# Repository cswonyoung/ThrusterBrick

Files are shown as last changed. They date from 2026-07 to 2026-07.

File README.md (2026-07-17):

# ZnO Nanovoid Process — document set

**Author:** Croft Swonyoung
**License:** CC0 1.0 Universal (public domain dedication) — see `LICENSE`
**Contents:** two application lines in one set — `docs-rotor/` (150 mm rotor/generator, 19 files, complete) and `docs-flight/` (300 mm flying machine, under construction). See `MANIFEST.md`.

To the extent possible under law, Croft Swonyoung has waived all copyright and
related or neighbouring rights to every file in this set and dedicated them to
the public domain worldwide. You may copy, modify, build on, and redistribute
them, including commercially, without permission. **No warranty** — see `LICENSE`.

## Cite / DOI
Archived on Zenodo: **10.5281/zenodo.21224278** —
<https://doi.org/10.5281/zenodo.21224278>

## What's here
- `docs-rotor/` — the 150 mm **rotor / generator** line (19 documents, complete).
- `docs-flight/` — the 300 mm **flying-machine** line (under construction; a
  re-derivation plan + a seed integration SOP so far). Every document in both
  directories carries the CC0 dedication and the author's name inline (a banner in
  the HTML/Markdown files; a comment header in the DXF cut files).
- `LICENSE` — full CC0 1.0 legal code.
- `NOTICE.md` — short human-readable dedication + a note on patents/prior art.
- `MANIFEST.md` — the file list with descriptions.
- `CHANGELOG.md` — version history (what changed in each release).
- `CHECKSUMS.sha256` — SHA-256 of every file (integrity + the timestamping anchor).
- `TIMESTAMPING.md` — how the dated proof works and the one command to create it.
- `UPLOAD-CHECKLIST.md` — step-by-step durable-publication guide.

## Verify integrity
```
sha256sum -c CHECKSUMS.sha256
```

## Reproduce / publish
See `UPLOAD-CHECKLIST.md`. Short version: fill the date in `NOTICE.md`, run
`ots stamp CHECKSUMS.sha256`, then push copies to several independent archives
(Zenodo for a DOI, GitHub + a mirror → Software Heritage, Internet Archive,
Arweave/IPFS).

## Scope note
These documents describe the *fabrication* of a stacked nickel "nanovoid"
structure (grow ZnO nanotips → seed → electroless Ni-P → strip the template →
bond each foil to a silicon wafer → stack and seal the wafer cells under a common
vacuum). They specify how to build the article; they
do not, by themselves, establish what net energy or other output the finished
article produces. Anyone reproducing the work should measure inputs and outputs
directly, with controls. Open publication under CC0 is what makes that
independent verification possible.

This set covers **two end-use lines** built from the same fabrication chemistry:
- **`docs-rotor/` — 150 mm rotor / generator line** (complete). Includes an
  application-integration procedure, `ZnO-SOP-070` (a self-driven rotor test rig).
- **`docs-flight/` — 300 mm flying-machine line** (under construction). The wafer
  size cascades through the whole fabrication chain, so this line is re-derived on
  its own datum — see `docs-flight/300mm-re-derivation-plan.md`.

The integration procedures describe **test rigs for measuring the hypothesised
force**, written to be safe and informative whether or not any net force exists,
and claiming nothing.

## Background & attribution
The tapered-nanocavity geometry in this process is motivated by:

> M. E. McCulloch, "Can Nano-Materials Push Off the Vacuum?",
> *Progress in Physics*, **16** (2), 92–93 (2020).

which argues — from the theory of *quantised inertia* (QI) — that arrays of
asymmetric sub-~129 nm cavities could experience a net force from the quantum
vacuum. Quantised inertia is a non-mainstream theory and the predicted effect is
unverified; this set documents only the *fabrication* of such a structure.
Whether a finished stack produces any net force is an open question to be settled
by direct measurement (see the scope note above). Credit for the underlying idea
is McCulloch's; responsibility for reducing it to a build process — and for any
errors in doing so — is the author's.

Documentation for this release was prepared with assistance from Claude
(Anthropic), reflected in the git commit history.

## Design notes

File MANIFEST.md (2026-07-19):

# Manifest — ZnO Nanovoid Process document set

All files are dedicated to the public domain under CC0 1.0 (see `LICENSE`). This
one set covers **two end-use lines** built from the same fabrication chemistry,
in two directories:

- **`docs-rotor/` — 150 mm rotor / generator line** (19 files, complete).
- **`docs-flight/` — 300 mm flying-machine line** (under construction).

## `docs-rotor/` — 150 mm rotor / generator line

| # | File | Description |
|---|---|---|
| 1 | `ZnO-DR-001_carrier_bath_design_reference.html` | Carrier & bath design reference (round) |
| 2 | `ZnO-DR-002_carrier_build_detail.html` | Carrier build detail (round plates, circular O-ring) |
| 3 | `ZnO-DR-003_immersion_carrier_cut_set.html` | Immersion & seeding carrier cut set (round) |
| 4 | `ZnO-DR-004_carrier_cutfile_nesting.html` | Carrier cut-file nesting (round) |
| 5 | `ZnO-DR-005_strip_carrier_cut_set.html` | Strip carrier cut set (round) |
| 6 | `ZnO-DR-006_wafer_chuck_cut_set.html` | Wafer bonding chuck cut set |
| 7 | `ZnO-SOP-010_nanotip_growth_10mM_depletion.md` | SOP-010 ZnO nanotip growth (10 mM depletion; ⌀156 / 0.15 mm Zn) |
| 8 | `ZnO-SOP-020_APTES_Ag_seeding.md` | SOP-020 APTES functionalisation & Ag seeding |
| 9 | `ZnO-SOP-030_electroless_NiP_plating.md` | SOP-030 electroless Ni-P plating |
| 10 | `ZnO-SOP-040_caustic_strip_clean_dry.md` | SOP-040 caustic strip / bulk clean / dry |
| 11 | `ZnO-SOP-050_phase1_wafer_bond_rim_trim.md` | SOP-050 Phase-1 wafer die-attach, chemical de-rim & final clean |
| 12 | `ZnO-SOP-060_phase2_vacuum_stack_close.md` | SOP-060 Phase-2 common-vacuum stack close (+ App. A application-agnostic ruggedization variant) |
| 13 | `ZnO-SOP-070_rotor_generator_integration.md` | SOP-070 Rotor integration & commissioning (self-driven rotor / thrust-hypothesis test) |
| 14 | `ZnO-SP-001_consolidated_shop_packet.html` | Consolidated shop packet |
| 15 | `ZnO_cut_PP_half.dxf` | Cut file — 1/2 in PP (strip backer, round) |
| 16 | `ZnO_cut_PP_threeEighth.dxf` | Cut file — 3/8 in PP (strip clamp frame, round) |
| 17 | `ZnO_cut_PVDF_quarter.dxf` | Cut file — 1/4 in PVDF (immersion/seeding carrier, round) |
| 18 | `ZnO_cut_frame_PVDF.dxf` | Cut file — PVDF clamp frame (RETIRED — no butyl mask) |
| 19 | `ZnO_cut_platen_alum.dxf` | Cut file — aluminium wafer bonding chuck |

## `docs-flight/` — 300 mm flying-machine line (🚧 under construction)

Naming: the 150 mm step numbers with a `-300` suffix (e.g. `ZnO-SOP-010-300`).

| File | Description | Status |
|---|---|---|
| `300mm-datum-reference.md` | Master datum — the locked dimensions every 300 mm doc cites | **locked** (a few `[confirm]`s) |
| `300mm-re-derivation-plan.md` | What changes from the 150 mm datum, per document | working plan |
| `ZnO-SOP-010-300_nanotip_growth_10mM_depletion.md` | SOP-010 ZnO nanotip growth (⌀306 blank, 4–6 L bath; ZnO seed layer) | **re-derived** (Rev 1.1) |
| `ZnO-SOP-020-300_APTES_Ag_seeding.md` | SOP-020 APTES functionalisation & Ag seeding | **re-derived** (Rev 1.0) |
| `ZnO-SOP-030-300_electroless_NiP_plating.md` | SOP-030 electroless Ni-P plating (⌀280 active; ~8–12 L bath) | **re-derived** (Rev 1.0) |
| `ZnO-SOP-040-300_caustic_strip_clean_dry.md` | SOP-040 caustic strip / bulk clean / dry (void-clear time unchanged) | **re-derived** (Rev 1.0) |
| `ZnO-SOP-050-300_phase1_wafer_bond_rim_trim.md` | SOP-050 Phase-1 wafer die-attach (300 mm wafer), de-rim & clean | **re-derived** (Rev 1.0) |
| `ZnO-SOP-060-300_phase2_vacuum_stack_close.md` | SOP-060 Phase-2 common-vacuum stack close (+ App. A ruggedization, 300 mm) | **re-derived** (Rev 1.0) |
| `ZnO-SOP-080-300_flying_vehicle_integration.md` | Flying-vehicle integration (staged lift demonstrator) | **seed** — still 150 mm-based; re-derive |
| `ZnO-DR-001-300_carrier_bath_design_reference.html` | Carrier & bath design reference | **re-derived** (Rev 1.0) ¹ |
| `ZnO-DR-002-300_carrier_build_detail.html` | Carrier build detail | **re-derived** (Rev 1.0) ¹ |
| `ZnO-DR-003-300_immersion_carrier_cut_set.html` | Immersion & seeding carrier cut set | **re-derived** (Rev 1.0) ¹ |
| `ZnO-DR-004-300_carrier_cutfile_nesting.html` | Carrier cut-file nesting (500 × 600 bed, 1 plate/sheet) | **re-derived** (Rev 1.0) ¹ |
| `ZnO-DR-005-300_strip_carrier_cut_set.html` | Strip carrier cut set | **re-derived** (Rev 1.0) ¹ |
| `ZnO-DR-006-300_wafer_chuck_cut_set.html` | Wafer bonding chuck cut set (⌀300; no waterjet) | **re-derived** (Rev 1.0) ¹ |
| `ZnO-SP-001-300_consolidated_shop_packet.html` | Consolidated shop packet (300 mm; ZnO seed layer at op 10) | **re-derived** (Rev 1.1) |
| `ZnO_cut_PP_half_300.dxf` | Cut file — 1/2 in PP strip backer (⌀350 carrier; ×16 M4 on ⌀330) | **generated** ✓ |
| `ZnO_cut_PP_threeEighth_300.dxf` | Cut file — 3/8 in PP strip clamp frame (window ⌀280) | **generated** ✓ |
| `ZnO_cut_PVDF_quarter_300.dxf` | Cut file — 1/4 in PVDF immersion/seeding carrier (2 beds: window+handle, back/mask) | **generated** ✓ |
| `ZnO_cut_platen_alum_300.dxf` | Cut file — aluminium wafer chuck (⌀340 / recess ⌀300.5; no waterjet) | **generated** ✓ |
| `ZnO_cut_PP_half_300.svg` | To-scale plan (generated) — strip backer | drawing |
| `ZnO_cut_PP_threeEighth_300.svg` | To-scale plan (generated) — strip clamp frame | drawing |
| `ZnO_cut_PVDF_quarter_300.svg` | To-scale plan (generated) — immersion/seeding carrier (2 beds) | drawing |
| `ZnO_cut_platen_alum_300.svg` | To-scale plan (generated) — wafer chuck | drawing |
| `gen_round_dxf_300.py` | Parametric generator — emits the DXF cut set + to-scale SVG plans from the datum (stdlib; validate DXFs with ezdxf) | tool |

¹ Text/table dimensions are on the 300 mm datum. Each cut-set/nesting doc now embeds a **to-scale plan generated from the DXF geometry** (`ZnO_cut_*_300.svg`); the remaining hand drawings are schematic context.

**The 300 mm fabrication line and tooling are complete:** SOP-010–060-300,
DR-001–006-300, SP-001-300, the DXF cut set, and the reproducible **generator +
to-scale plan drawings**, all at the locked datum. DXFs validated with ezdxf.
(`ZnO_cut_frame_PVDF` stays retired — no 300 mm version.) Remaining: the
flying-integration procedure `ZnO-SOP-080-300` is still a 150 mm-based **seed**,
to be re-derived when the flyer / airframe is defined.

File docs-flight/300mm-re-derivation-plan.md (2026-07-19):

# 300 mm re-derivation plan — flying-machine line

Working plan for deriving the 300 mm flight line (`docs-flight/`) from the
established 150 mm rotor line (`../docs-rotor/`) in this same repository. The
**chemistry is unchanged**; what changes is geometry,
tooling, bath scale, and mass. Numbers below are **scaled estimates to confirm**,
not final — decisions the maker must lock are flagged **[DECIDE]**.

> **Tracking note:** the 150 mm line is a moving target — when a rotor-line SOP
> revs, the corresponding `-300` doc must track it (e.g. the **ZnO seed layer**
> added at 150 mm Rev 3.0 was carried into `ZnO-SOP-010-300` Rev 1.1; see §2).

## 1. Datum change (150 mm → 300 mm)

| Parameter | 150 mm (current) | 300 mm (proposed) | Note |
|---|---|---|---|
| Wafer diameter | ⌀150.0 | **⌀300.0** | — |
| Wafer thickness | 0.675 mm | **0.775 mm** | SEMI standard for 300 mm — **[DECIDE/confirm]** |
| Active (etched) region | ⌀130 (10 mm margin) | **⌀280** (keep 10 mm margin) | or scale margin → ⌀260 **[DECIDE]** |
| Zinc foil thickness | 0.15 mm | **0.15 mm (unchanged)** | template thickness is wafer-independent — **[confirm]** |
| Zinc handling rim | 13 mm | **13 mm (unchanged)** | or scale **[DECIDE]** |
| Zinc blank | ⌀156 | **⌀306** | = active ⌀280 + 2×13 rim |
| Ni-P thickness | 25 µm | **25 µm (unchanged)** | thickness is diameter-independent |
| Per-cell pitch | ≈0.78 mm | **≈0.875 mm** | wafer 0.775 + Ni-P 0.025 + bond ~0.075 |
| Per-cell mass | ≈32 g | **≈140 g** | ~4.4× (Si ⌀300×0.775 ≈128 g + Ni-P ≈12 g + bond) |
| Active area / cell | (⌀130) | **~4.6×** | (280/130)² — drives thrust *and* handling |

## 2. Per-document work

**Fabrication chain (re-derive each at the new datum):**
- **SOP-010** (ZnO growth) — ⌀306 zinc blank; bath volume ~4× (vessel ⌀360–400+);
  growth chemistry unchanged, immersion geometry scaled. **Done through Rev 1.1**,
  which tracks the 150 mm Rev 3.0 **ZnO seed layer** (zinc-acetate coat + 300 °C
  anneal, replacing bare-foil self-seeding for c-axis-vertical uniformity): recipe
  identical at both scales; what scales at 300 mm is the handling — ~10–15 mL per
  flood coat, a ≥ ⌀320 anneal plate with **oven preferred** over a hotplate for
  edge-to-edge temperature, and centre-to-edge seed-tint QC. No acid contact after
  seeding (ZnO dissolves in weak acids).
- **SOP-020** (APTES + Ag seed) — seeding carrier scaled to ⌀306; glovebox/vapour
  chamber must clear the larger coupon; reagent volumes ~4×.
- **SOP-030** (electroless Ni-P) — bath ~4× (~6–10 L; vessel ⌀360–400+); plating
  chemistry and 25 µm target unchanged; longer fill/agitation for the larger area.
- **SOP-040** (caustic strip / clean / dry) — strip time set by **area not
  thickness**, so ~4× the H₂/zincate load and bath charge; the ~10–12 h
  void-clearing is void-geometry-limited (unchanged); larger dry fixtures.
- **SOP-050** (Phase-1 wafer bond + de-rim) — ⌀300 wafer chuck; bigger bond fixture;
  chemical de-rim self-stops at ⌀280; handle 300 mm wafer fragility.
- **SOP-060** (Phase-2 vacuum stack close) — ⌀300 stack; envelope + chamber sealer
  must clear ⌀300+; getter sized to ~4× area/outgassing; platens ⌀≥300 (step to
  ¼″ likely needed for flatness under load); **N and mass budget re-computed** (see §3).

**Design references (rewrite to the ⌀306 datum, bump revs):**
- **DR-001…005** — carrier/bath/immersion/strip references at the new diameter;
  larger vessels; re-do nesting (a ⌀340+ carrier likely = 1 plate per larger sheet).
- **DR-006** — wafer bonding chuck for 300 mm.

**DXF cut set (regenerate all at the new datum):**
- Carrier plate: outer ~⌀340–360 **[DECIDE]**, window ⌀280, coupon pocket ⌀306.3,
  O-ring groove ~⌀293, bolt circle ~⌀324 ×16 M4 **[DECIDE]** (more bolts for the
  larger plate); PP/PVDF backer + clamp frame scaled; aluminium wafer chuck → ⌀300.
- New/larger stock sizes — confirm bed/sheet size against your cutter.

**Application integration:**
- **SOP-080** (flying-vehicle) — re-derive against the 300 mm ruggedized puck
  handoff (§4) and the new masses; complete the `[TBD]` fields (per-puck thrust,
  vehicle mass, T/W). Currently in `docs/` as a 150 mm-based **seed**.

**Consolidated shop packet:**
- **SP-001** — full rewrite to the 300 mm datum (index, purchasing, station list,
  bath volumes, fixtures).

## 3. Mass / stack recompute (flyer-critical)

- Per-cell ≈140 g at 0.875 mm pitch. A stack of N cells ≈ **0.14N kg** active +
  platens + envelope/getter.
- **Honest scaling caveat:** active area (~4.6×) and cell mass (~4.4×) scale
  *together*, so going to 300 mm raises **absolute** thrust and mass in step —
  **thrust-to-weight is roughly scale-invariant.** The 300 mm choice buys larger
  absolute thrust per layer and fewer cells/interfaces for a given area, **not**
  a better lift ratio. Confirm the intended rationale before committing, and keep
  T/W > 1 as the open, to-be-measured question (SOP-080).

## 4. Ruggedization at 300 mm (SOP-060 Appendix A equivalent)

- Edge-cushion **rim strip**: width = stack height H; length = π(D + s) ≈
  **π(301) ≈ 946 mm**; same 50 A / 1.0 mm platinum-silicone, E595, vacuum-baked.
- Optional recessed **end-ring**: OD 300, ID ≥ (active ⌀280 + margin), recessed
  into the platen (never proud in the preload path).
- **Carrier pot**: larger, heavier; same filled low-exotherm epoxy discipline;
  CoG/mass budget set by the flyer's needs, not a rotor's 128 G.

## 5. Equipment / cost implications

- ~4× reagent volumes; vessels, glovebox, and **chamber sealer** all sized for
  ⌀300+ — the sealer clearance is a likely long-lead/cost item.
- 300 mm wafers: higher unit cost, more fragile handling, larger clean staging.

### 5.1 Cutter (router) bed sizing
The bed size is driven by the largest single part — the **shared carrier plate**.
On the 150 mm line that plate is ⌀190 (⌀156 coupon) and cuts ~1/sheet on a
~300 × 287 mm bed. At 300 mm the coupon (zinc blank) is ⌀306, so the carrier
scales to roughly **⌀350–380** (straight 2× → ⌀380; coupon ⌀306 + the same
absolute land/bolt-circle margins → ⌀340–356). Add ~30–50 mm workholding all
round → stock blank ~⌀450–480.

| Usable cutting envelope | Fit |
|---|---|
| ~**500 × 500 mm** (minimum) | one ⌀380 carrier with clamps; tight |
| ~**600 × 600 mm** (24″×24″, recommended) | carrier + companion parts (clamp frame, backer) without re-fixturing |
| ~**600 × 900** or **1220 × 1220** (4′×4′) | nesting / full-sheet stock |

Heuristic: **≈ double each dimension of the current ~300 × 287 bed → ~600 × 600**.

**DECIDED (2026-07-15):** target a standard **500 × 600 mm** bed. The carrier is
held to ⌀≤~380 to fit with clamp margin; **lock the carrier at ⌀350** (see
`300mm-datum-reference.md`) so clamping stays comfortable on the 500 mm axis (use
the 600 mm axis for clamp length; ⌀350 + ~2×50 mm ≈ ⌀450 blank fits 500 × 600).

**Caveat — the aluminium chuck needs another machine.** The carriers are plastic
(PVDF/PP/PEEK) and suit the 500 × 600 router. The **aluminium wafer chuck at
⌀300+** is a heavier cut; **waterjet is ruled out on cost**, so the options are a
**rigid mill**, a **slow router pass** (right bit/feeds, stepped depths),
**outsourcing** just that part, or reconsidering the chuck material (a thick, flat
polymer or cast tooling-plate alternative) — decide when the chuck is designed.

## 6. Open decisions (flag before building)

1. Wafer thickness (0.775 mm standard vs thinned) — **default 0.775 mm** in the
   datum reference; confirm.
2. Active-region margin (fixed 10 mm → ⌀280, or scaled) — **default 10 mm** (⌀280);
   confirm.
3. Zinc rim width and blank ⌀306 vs scaled — **default 13 mm → ⌀306**; confirm.
4. Carrier outer ⌀ and bolt pattern — **RESOLVED: ⌀350 outer, bolt circle ⌀330 ×16
   M4** (bounded by the 500 × 600 bed; see the datum reference); confirm bolt
   count/size against your cutter.
5. **Numbering — RESOLVED:** `-300` suffix on the 150 mm step numbers
   (`ZnO-SOP-010-300`, `ZnO-DR-001-300`, `ZnO_cut_<part>_300.dxf`).
6. **300 mm rationale — RESOLVED:** handling / throughput (fewer, larger parts per
   unit active area); T/W ~scale-invariant, so the win is process efficiency, not
   lift ratio.

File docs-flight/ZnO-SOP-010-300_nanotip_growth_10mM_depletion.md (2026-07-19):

<!-- Public Domain Dedication: CC0 1.0 Universal -->
> **Public Domain · CC0 1.0 Universal.** Author: **Croft Swonyoung**. To the extent possible under law, the author has waived all copyright and related or neighbouring rights to this document and dedicates it to the public domain worldwide (CC0 1.0). No warranty. See `LICENSE` or <https://creativecommons.org/publicdomain/zero/1.0/>.
>
> Part of the *ZnO nanovoid process* document set (300 mm flying line). Verify file integrity against `CHECKSUMS.sha256`.

---

> **300 mm line · derived from the 150 mm `ZnO-SOP-010` Rev 3.0.** The growth
> **chemistry, seed-layer recipe, temperatures, and target tip geometry are identical**
> to the 150 mm procedure — only the **substrate blank, vessel, bath volume, and
> seed-coat/anneal handling** scale with the larger wafer. All dimensions come from
> `300mm-datum-reference.md`; this SOP does not restate them independently.

---

# Working Bath Procedure & Specification

## Seeded Hydrothermal Growth of ZnO Nanotips on Zinc Foil (300 mm)
### 10 mM Equimolar Zn(NO₃)₂·6H₂O / HMTA — Depletion Run (ZnO seed layer; no post-growth acid etch)

| Field | Value | Field | Value |
|---|---|---|---|
| Document no. | ZnO-SOP-010-300 | Revision | 1.1 |
| Effective date | ____________ | Supersedes | Rev 1.0 |
| Author | Croft Swonyoung | Approved by | ____________ |
| Process | ACG / hydrothermal | Deposit face | One side (back masked) |

---

## 1. Purpose and scope

This procedure grows a dense, vertically oriented array of ZnO nanotips on one face of zinc foil by seeded aqueous chemical (hydrothermal) growth. A **ZnO seed layer** — zinc-acetate-derived nanocrystals coated onto the cleaned foil and annealed (§6.3) — sets a dense, uniform, (0001)-up nucleation template, so rod orientation is decoupled from the random grain orientations of the rolled foil and the array comes out c-axis vertical with a tight size distribution. A single charge of dilute (10 mM) equimolar zinc nitrate / hexamethylenetetramine solution is then held at 90 °C and run to depletion; the declining supersaturation of the depleting bath produces the tapered tips without any post-growth acid treatment.

**Target geometry (per crystal):** base 70–120 nm (measured across the hexagonal flats), height < 300 nm, tapered to a point, densely packed, c-axis vertical. *(Unchanged from the 150 mm line — tip geometry is set by the bath chemistry, not the coupon size.)*

**Substrate:** zinc foil, **0.15 mm thick**, cut as a **⌀306 round blank** (the downstream etch/plate/strip flow defines a **⌀280 active area** inside a **13 mm handling rim**, to back a **300 mm silicon wafer** — see `300mm-datum-reference.md`). Mounted in a carrier that masks the reverse face so growth occurs on one side only.

---

## 2. Definitions and interpretation

- **"Acid etch" (post-growth)** — the tip-sharpening step applied *after* growth — is deliberately omitted here; taper is obtained from bath depletion alone.
- **Light etch (pre-growth)** — a brief, separate dilute-**acetic-acid** dip *before* growth (§6.2) that strips the native oxide and presents a fresh surface for the seed coat. It is retained, and is **not** the same step as the omitted post-growth etch. Nucleation density is set primarily by the seed layer, not the etch.
- **ZnO seed layer (pre-growth)** — a coat of ~5–10 nm ZnO nanocrystals formed by flood-coating the cleaned foil with dilute zinc acetate in ethanol and annealing at ~300 °C (§6.3). The seeds carry a (0001)-up texture, so rods nucleate dense, uniform, and c-axis vertical regardless of the foil's grain orientations. **Because ZnO dissolves in weak acids, no acid may contact the foil after the seed layer is applied.** *Naming:* always write "ZnO seed layer" for this step — the *silver seeding* of ZnO-SOP-020-300 (catalytic seed for electroless Ni-P) is a different step, and the two must stay unambiguous across the document set.
- **Depletion run:** running the fresh bath until the zinc precursor is spent and no fresh precipitate forms. A single, un-replenished charge self-limits rod height, which is how sub-300 nm height is held.
- **Base diameter:** dimensions are stated face-to-face (across flats). Across corners is ~1.155× larger; fix the across-flats convention for all SEM measurements.

---

## 3. Health, safety and environment

Consult the SDS for each reagent before starting. Key hazards:

- **Hexamethylenetetramine (HMTA)** — flammable solid; on heating in water it releases formaldehyde and ammonia. Weigh and run in a fume hood.
- **Zinc nitrate hexahydrate** — oxidiser; skin/eye/respiratory irritant. Keep away from combustibles.
- **Dilute acetic acid** (light-etch dip, ~2–5 % v/v) — irritant to eyes and skin at working strength; pungent vapour. Gloves and goggles. The **glacial acetic acid concentrate** used to make dilutions is corrosive and combustible — dilute in a fume hood, and always add acid to water, never water to acid.
- **Hot solution** — the 90 °C aqueous bath is a burn/scald hazard, and at 300 mm the **bath is ~4× larger (4–6 L) and heavier** — use a stable, well-supported vessel and safe lifting practice. Use a loosely covered (vented) vessel; never seal a hot bath and keep ≤ 95 °C to avoid pressure build-up.
- **Absolute ethanol** (seed solution and inter-coat rinse) — highly flammable liquid and vapour. Keep away from hot surfaces and all ignition sources; work with small volumes; cap containers. Complete all ethanol steps and let the face dry **before** the anneal heat-up.
- **Zinc acetate dihydrate** — eye/skin irritant; zinc-bearing (heavy-metal waste stream).
- **Seed anneal (~300 °C)** — severe burn hazard; at 300 mm the anneal plate is large (≥ ⌀306) and holds substantial heat — it and the foil stay hot long after heating stops. Handle with tongs/heat gloves and allow full cool-down.
- **PPE:** nitrile gloves, safety goggles, lab coat; all HMTA weighing and bath heating in a fume hood.
- **Waste:** the spent bath carries dissolved and particulate zinc (now ~4× the volume). Collect as aqueous heavy-metal waste; do not pour to drain. Neutralise/dispose per local regulations. Spent etch dip carries dissolved zinc acetate — same heavy-metal stream.

---

## 4. Materials, reagents and equipment

### 4.1 Reagents

- Zinc nitrate hexahydrate, Zn(NO₃)₂·6H₂O, ACS grade (M = 297.48 g/mol).
- Hexamethylenetetramine (HMTA), C₆H₁₂N₄, ≥ 99 % (M = 140.19 g/mol).
- Deionised water, Type I/II (≥ 18 MΩ·cm preferred), for bath make-up and rinsing.
- Acetone and isopropanol (IPA), reagent grade, for degreasing.
- Dilute acetic acid, ~2–5 % v/v (≈ 0.35–0.9 M), for the pre-growth light etch; dilute from glacial acetic acid (≥ 99 %) with DI water.
- Zinc acetate dihydrate, Zn(CH₃COO)₂·2H₂O, ACS grade (M = 219.51 g/mol), for the seed solution.
- Absolute ethanol (≥ 99.5 %), for seed-solution make-up and the inter-coat rinse.
- Dry nitrogen (or clean, oil-free compressed air) for drying.

### 4.2 Equipment

- Hotplate or water/oil bath, stable to 90 ± 2 °C, **sized for the larger 4–6 L charge** (heat-up is slower — allow for it), with a calibrated thermometer/thermocouple in the bath.
- **Wide inert growth vessel** (borosilicate or PP) able to submerge the **⌀306 foil with ~10–20 mm clearance — inner ⌀ ~340–360 mm**, ~4–6 L, with a loose lid/watch-glass cover.
- Substrate carrier that masks the reverse face and holds the **⌀306** foil face-down or tilted 15–45° (a larger, floppier coupon than the 150 mm line — support it fully to keep it flat; see §6.6).
- Heat source capable of **300 ± 25 °C across the full ⌀306 blank** for the seed anneal: a flat aluminium anneal plate **≥ ~320 mm** on a hotplate large enough to heat it evenly, or (preferred at this size for temperature uniformity) a lab/convection oven that accepts the plate flat; tongs/heat gloves.
- Pipette (~10–20 mL) and ethanol wash bottle for the seed coats; a clean, level surface large enough for the ⌀306 blank.
- Analytical balance (0.1 mg), volumetric glassware, PTFE-tipped tweezers, timer, sonicator large enough for the ⌀306 coupon, drying stand.

---

## 5. Bath specification

| Parameter | Specification | Notes / tolerance |
|---|---|---|
| Chemistry | Zn(NO₃)₂·6H₂O + HMTA, equimolar | 1 : 1 molar ratio |
| Concentration | 10 mM each | Dilute — thin bases, low per-rod budget |
| Solvent | Type I/II DI water | ≥ 18 MΩ·cm preferred |
| Zn(NO₃)₂·6H₂O loading | 2.975 g per litre | = 0.010 mol/L × 297.48 g/mol |
| HMTA loading | 1.402 g per litre | = 0.010 mol/L × 140.19 g/mol |
| As-mixed pH | ~5.5–6.5 | Do not adjust; not externally buffered |
| Temperature | 90 °C | Acceptable 88–92 °C; never seal, ≤ 95 °C |
| Agitation | Static (no stirring) | Convection re-feeds supersaturation and blunts tips |
| Charge | Single, un-replenished | Defines zinc budget → self-limited height |
| Run mode | Run to depletion | End when solution clears / no fresh precipitate |
| Typical run time | ~45–90 min | **Calibrate on first run;** record actual time |
| Substrate orientation | Face-down or tilted | Lets homogeneous particles fall clear of the face |

> **Concentration and temperature are unchanged from the 150 mm line** — the per-rod
> zinc budget that sets tip geometry is a *concentration* effect, independent of
> coupon size. The larger coupon simply needs more litres of the same 10 mM bath.

### 5.1 Reagent quantities by bath volume

| Bath volume | Zn(NO₃)₂·6H₂O | HMTA |
|---|---|---|
| 4.0 L | 11.900 g | 5.608 g |
| 5.0 L | 14.875 g | 7.010 g |
| 6.0 L | 17.850 g | 8.412 g |

**Sizing:** use the smallest volume that fully submerges the ⌀306 foil with ~10–20 mm clearance — typically **~4–6 L** in a ~⌀340–360 mm vessel. Scale masses linearly: mass = (2.975 g/L Zn(NO₃)₂ or 1.402 g/L HMTA) × volume in L.

### 5.2 Seed solution specification

*(Chemistry identical to the 150 mm line — only the per-coat flood volume scales with the ⌀306 face.)*

| Parameter | Specification | Notes / tolerance |
|---|---|---|
| Chemistry | Zn(CH₃COO)₂·2H₂O in absolute ethanol | Seed coat only — never enters the growth bath |
| Concentration | 5 mM | **0.110 g per 100 mL** ethanol |
| Make-up | Dissolve with brief sonication or mild warming (< 40 °C) | Must be fully clear before use |
| Coats | 3–5 flood coats, **~10–15 mL each** for the ⌀306 face | Each: flood 10–20 s → ethanol rinse → N₂ dry (§6.3) |
| Anneal | 300 ± 25 °C, 20–30 min, in air | Decomposes acetate to ~5–10 nm ZnO seeds, (0001)-up texture |
| Shelf life | ≤ ~1 week, sealed | Make fresh preferred; discard if hazy (slow hydrolysis) |

---

## 6. Procedure

### 6.1 Blank the round substrate

Cut the **⌀306 round zinc blank** from 0.15 mm zinc foil stock **before** any cleaning. The cut sits 13 mm outside the ⌀280 active zone, so it never touches the nanostructured area, and the rim it forms is sacrificial (dissolved at the ZnO-SOP-050-300 de-rim) — so edge finish is uncritical. The one spec that matters is that the blank drops cleanly into the carriers' **⌀306.3 locating pocket** (ZnO-DR-003-300 / ZnO-DR-005-300).

1. **Method (in order of preference for a ⌀306 disc):**
   - **Adjustable rotary circle cutter** — set to **153 mm radius** on a backing mat; no tooling, and practical at this larger diameter (a ⌀306 steel-rule die or punch is large and costly). Hand-guided, so verify roundness/diameter.
   - **Custom ⌀306 steel-rule die / hollow punch** — ideal repeatability for batches if the tooling cost is justified; press-driven.
   - *(Laser is acceptable but zinc fume needs extraction.)* **Do not use the CNC router** — it deflects and grabs 0.15 mm foil and throws swarf; the larger, floppier ⌀306 blank is even more prone to this.
2. **Backing:** cut over end-grain wood, a poly cutting board, or a self-healing mat so the blade fully severs the foil without tearing.
3. **Burr:** orient the tool so any burr lands on the **rim** (the sacrificial, de-rimmed side); knock down a burr that would keep the blank from seating.
4. **Fit check:** confirm the blank is round and drops flush into the ⌀306.3 carrier pocket; deburr or retrim if proud. **Flatness:** the larger blank is floppier — keep it flat during handling and store between flat supports.
5. Handle by the rim only; keep the future growth face clean.

### 6.2 Substrate preparation — before-growth cleaning

1. Handle the foil only with PTFE-tipped tweezers by an edge; never touch the growth face. The ⌀306 coupon is large — support the whole disc during transfers so it does not fold.
2. Sonicate 5 min in acetone.
3. Sonicate 5 min in fresh isopropanol.
4. Sonicate 5 min in DI water to remove solvent residue.
5. **Light etch:** dip 15–30 s in dilute acetic acid (~2–5 % v/v) to strip the native oxide and open nucleation sites. **Calibrate the time on the first run** and keep it a controlled parameter; over-etching still thins and roughens the foil.
6. **Immediately** rinse under copious flowing DI water to stop the etch; do not let the freshly etched surface sit in air.
7. Blow dry at once with N₂ (or clean air), sheeting water off the face to avoid spots.
8. Proceed **immediately** to the seed-layer coat (§6.3); do not let the freshly etched surface sit in air. (Carrier mounting now happens after the seed anneal — §6.3 step 8.)

> **Note — light etch.** Removing the passivating native oxide presents a fresh, wettable surface for the seed coat; the post-growth tip-sharpening etch remains omitted. ZnO dissolves readily in weak organic acids — which is also why **no acid may touch the foil after §6.3**. With the seed layer setting nucleation density, over-etching gains nothing: hold to the short end of the dip window unless wetting is visibly poor.

### 6.3 ZnO seed layer (coat and anneal)

Rolled zinc foil is polycrystalline with random grain orientations; rods nucleating directly on bare foil inherit that spread and grow at scattered tilts. This step lays down a dense, uniform template of ~5–10 nm ZnO nanocrystals with (0001)-up texture, so the rods grow c-axis vertical with a tight base-diameter distribution, independent of the grains beneath. Dense, uniform nucleation also self-corrects residual tilt: off-vertical rods run into neighbours and terminate while vertical rods win. Over the ⌀280 active field this matters doubly — orientation and size spread must hold **centre-to-edge**, not just locally.

**No acid contact from this point on — the acetic dip dissolves ZnO seeds.**

1. Perform §6.2 in full (degrease, light etch, rinse, dry) and continue directly — do not pause between etch and first coat.
2. Lay the foil flat, growth face up, on a clean, level surface large enough to support the full ⌀306 disc. Confirm level — on a face this large, an out-of-level surface pools the seed solution to one side and grades the coat.
3. Flood the growth face with seed solution (§5.2) from a pipette — **~10–15 mL for the ⌀306 face**, working quickly edge to edge so the whole face wets before the first-applied region dries. Let stand 10–20 s.
4. Rinse gently with clean absolute ethanol from a wash bottle, then blow dry with N₂, sheeting toward the rim. The rinse is what leaves a sparse adsorbed layer rather than drying rings — **do not skip it.**
5. Repeat steps 3–4 for a total of **3–5 coats**.
6. **Anneal:** lay the foil dead flat on the ≥ ⌀320 aluminium anneal plate, growth face up (weight the rim with a flat ring if it lifts — the large blank is prone to lifting at the edge), ramp gently to **300 ± 25 °C**, hold **20–30 min** in air, then cool slowly in place. An oven is preferred at this size — a hotplate smaller than the plate leaves the rim cold and the seed texture non-uniform; if a hotplate must be used, verify the plate reaches temperature edge-to-edge before counting the hold. Stay far below zinc's 419.5 °C melting point. The face dulls slightly from thermal oxide — acceptable; the entire Zn/ZnO template dissolves at ZnO-SOP-040-300.
7. *Optional density lever (qualify before adopting):* repeat the full coat-set + anneal cycle a second time for denser seeding.
8. Mount in the carrier (reverse face masked) and proceed to bath preparation and growth promptly. The anneal fully softens the zinc — the ⌀306 foil comes off the plate flatter but floppier, and at this diameter it will fold under its own weight if lifted by an edge; slide it onto a flat support and handle by the rim with the disc fully supported.

### 6.4 Bath preparation

1. Charge the vessel with ~90 % of the target DI water volume (4–6 L).
2. Weigh Zn(NO₃)₂·6H₂O and HMTA to the quantities in §5.1; record actual masses.
3. Dissolve the zinc nitrate fully with gentle stirring, then dissolve the HMTA; stir until completely clear.
4. Make up to final volume with DI water. Optionally filter (0.2 µm) to remove stray particulates.
5. Cover and pre-heat the solution to 90 °C — **allow extra time for the larger charge to reach temperature.** Confirm with the in-bath probe before loading the substrate.

### 6.5 Growth run (to depletion)

1. Immerse the carried substrate, growth face down or tilted, into the 90 °C bath. Start the timer (t₀). Ensure no air bubbles are trapped on the face — a larger face traps bubbles more easily, so tilt on entry to sweep them off.
2. Hold at 90 °C, static and loosely covered. Do not stir, agitate, or replenish the bath.
3. Let the run proceed to depletion: the solution turns milky at peak nucleation, then clears as zinc is consumed. Endpoint = a clear (or markedly clarified) bath with no fresh precipitate forming.
4. Record the actual depletion time (expect ~45–90 min on the first calibration run) and the bath temperature profile. **Re-calibrate for this line:** the larger bath and coupon may shift the observed depletion time — treat the first 300 mm run as a fresh calibration.

### 6.6 Recovery — after-growth cleaning

1. At the endpoint, withdraw the substrate promptly, supporting the full ⌀306 disc.
2. Immediately rinse under copious flowing DI water to quench the reaction and float off loosely bound homogeneous particles. Do not wipe or brush the surface.
3. Optional, if loose powder persists: a few seconds of very gentle low-power DI sonication. **Caution** — aggressive sonication dislodges rods; use sparingly and inspect afterward.
4. Blow dry with N₂, holding the foil so water sheets off cleanly; avoid drying spots.
5. Optional consolidation dry: up to ~150–250 °C in air to drive off residual water (gentle ramp; the 0.15 mm foil thickness is unchanged from the 150 mm line, but the **larger ⌀306 disc has more unsupported area and is more warp-prone** — support it flat and ramp gently; stay far below the 419.5 °C zinc melting point). Not required for geometry.
6. Store the finished foil flat between clean flat supports, in a covered container.

---

## 7. Acceptance criteria and QC

- **Seed layer (post-anneal, pre-growth):** uniform faint tint change across the face, **centre-to-edge** — no rings, droplet marks, streaks, bare patches, or a visibly different rim (a cold-rim anneal shows up here). Rings, patches, or a graded tint → re-clean and re-seed before committing the growth run.
- **Visual (post-growth):** uniform matte white/grey coating over the growth face; no bare patches, no thick powdery cake. Over the larger ⌀280 active area, check uniformity **centre-to-edge** (a bigger face is more prone to edge-to-centre gradients from bath convection).
- **SEM (plan + cross-section) — base** (across flats) 70–120 nm; height < 300 nm; tips tapered to a point; densely packed without coalescing into a film; rods c-axis vertical and parallel in cross-section (tilt spread tight — the seeded array should not show splayed rods). Sample **multiple sites across the ⌀280 field**, not just the centre.
- **Process:** spent bath clear at pull; depletion time logged.
- **First-run gate:** the seed layer splits the same 10 mM single charge across more rods, so expect **denser, shorter, thinner** output than the unseeded expectation. Re-calibrate base diameter, height, packing, and verticality by SEM — with **cross-field uniformity** confirmed — on the first seeded 300 mm run before releasing the recipe to routine use.

**Expected first-pass output (10 mM depletion, seeded):** trends denser, shorter, and thinner-based than the unseeded expectation (base ~60–100 nm, height ~250–380 nm, strong taper) — treat those numbers as the upper envelope and let the first seeded run set the new baseline. If height still edges over 300 nm, reduce concentration toward ~8 mM (which depletes sooner and shorter) and re-qualify; if bases fall well under 70 nm, drop to 3 coats.

---

## 8. Troubleshooting

| Observation | Likely cause → corrective action |
|---|---|
| Height > 300 nm | Per-rod zinc budget too high → dilute toward 8 mM; confirm single charge; optionally drop to 88 °C. |
| Bases > 120 nm / merging | Too much lateral growth → lower concentration; verify not double-charged. |
| Bases < 70 nm / sparse | Weak nucleation → add seed coats (3 → 5) or a second coat-set + anneal cycle; verify the anneal reached ≥ ~275 °C across the whole plate (acetate does not fully decompose below that); improve degrease; transfer promptly between steps. |
| Rods tilted / splayed | Seed coat thin or patchy (foil grains showing through) → add coats or a second coat-set + anneal cycle; confirm the ethanol rinse after **every** coat; confirm no acid contact after seeding. |
| Rings / streaks in the array | Seed solution allowed to dry unrinsed, or the coating surface out of level → rinse with clean ethanol after every coat; level the surface; work the flood quickly edge to edge; discard hazy seed solution. |
| **Centre-to-edge non-uniformity** (new at 300 mm) | Seed-side: graded seed coat (out-of-level flood) or cold-rim anneal → level the coating surface; use an oven or verify edge-to-edge plate temperature. Growth-side: convection gradients over the larger face → keep strictly static and level; ensure even immersion depth; consider a deeper bath so the whole face sees similar hydrostatic/thermal conditions. |
| Blunt / flat tips | Bath not truly depleted, or convection re-fed it → confirm run to clear; keep strictly static. |
| Loose powdery deposit | Excess homogeneous nucleation settling on the face → keep face-down; filter make-up; gentler heat-up. |
| Foil thinned / warped / pitted | Light etch too long or acid too concentrated → shorten the dip; dilute the acid; rinse promptly. Support the large disc flat throughout. |
| Rods detached after rinse | Recovery too aggressive → gentler DI rinse; reduce or eliminate sonication. |

---

## 9. Waste and storage

- Collect spent baths and zinc-bearing rinse water (including the spent acetic etch, now zinc acetate solution) as aqueous heavy-metal waste; neutralise and dispose per local regulations. Do not drain-dispose. Volumes are ~4× the 150 mm line — size your waste collection accordingly.
- Spent seed solution and inter-coat ethanol rinses are **zinc-bearing flammable organic waste** — collect separately from the aqueous stream; do not drain-dispose.
- Store unused reagents dry and sealed; HMTA away from heat and ignition; zinc nitrate away from combustibles; glacial acetic acid away from oxidisers and bases; ethanol away from ignition sources; zinc acetate dry.
- Store finished substrates flat (between flat supports), dry, covered, and labelled with run ID and depletion time.

---

## 10. Revision history

| Rev | Date | Author | Change summary |
|---|---|---|---|
| 1.0 | __________ | Croft Swonyoung | **Initial release of the 300 mm flying-line variant, derived from the 150 mm `ZnO-SOP-010` Rev 2.2.** Substrate scaled to a **⌀306 round zinc blank** (⌀280 active + 13 mm rim, backing a 300 mm wafer per `300mm-datum-reference.md`); growth vessel to ~⌀340–360 mm / **4–6 L**; reagent-by-volume table re-tabulated for 4–6 L; blanking method favours the rotary circle cutter (153 mm radius) at this diameter; added centre-to-edge uniformity checks and large-floppy-coupon handling/flatness notes. **Growth chemistry, 10 mM concentration, 90 °C temperature, and target tip geometry are unchanged** — they are concentration/temperature effects independent of coupon size. |
| 1.1 | __________ | Croft Swonyoung | **Tracks the 150 mm `ZnO-SOP-010` Rev 3.0: added the ZnO seed layer** (new §6.3) — 5 mM zinc acetate dihydrate in absolute ethanol, 3–5 flood coats (**~10–15 mL each** at ⌀306) with ethanol rinse each, annealed 300 ± 25 °C / 20–30 min in air on a ≥ ⌀320 flat plate (oven preferred at this size for edge-to-edge temperature). Title changed from *Self-Seeded* to *Seeded*. Light etch retained as surface prep; **no acid contact after seeding**. Carrier mounting moved to after the seed anneal; §6.3–6.5 renumbered §6.4–6.6; seed-solution spec added as §5.2; reagents, equipment, HSE, QC (centre-to-edge seed-tint check; seeded-run recalibration gate), troubleshooting (cold-rim / graded-coat causes), and waste updated. Naming rule: "ZnO seed layer" here vs. "silver seeding" in ZnO-SOP-020-300. |

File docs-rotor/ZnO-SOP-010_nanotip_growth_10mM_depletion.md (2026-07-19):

<!-- Public Domain Dedication: CC0 1.0 Universal -->
> **Public Domain · CC0 1.0 Universal.** Author: **Croft Swonyoung**. To the extent possible under law, the author has waived all copyright and related or neighbouring rights to this document and dedicates it to the public domain worldwide (CC0 1.0). No warranty. See `LICENSE` or <https://creativecommons.org/publicdomain/zero/1.0/>.
>
> Part of the *ZnO nanovoid process* document set. Verify file integrity against `CHECKSUMS.sha256`.

---

# Working Bath Procedure & Specification

## Seeded Hydrothermal Growth of ZnO Nanotips on Zinc Foil
### 10 mM Equimolar Zn(NO₃)₂·6H₂O / HMTA — Depletion Run (ZnO seed layer; no post-growth acid etch)

| Field | Value | Field | Value |
|---|---|---|---|
| Document no. | ZnO-SOP-010 | Revision | 3.0 |
| Effective date | ____________ | Supersedes | Rev 2.2 |
| Author | Croft Swonyoung | Approved by | ____________ |
| Process | ACG / hydrothermal | Deposit face | One side (back masked) |

---

## 1. Purpose and scope

This procedure grows a dense, vertically oriented array of ZnO nanotips on one face of zinc foil by seeded aqueous chemical (hydrothermal) growth. A **ZnO seed layer** — zinc-acetate-derived nanocrystals coated onto the cleaned foil and annealed (§6.3) — sets a dense, uniform, (0001)-up nucleation template, so rod orientation is decoupled from the random grain orientations of the rolled foil and the array comes out c-axis vertical with a tight size distribution. A single charge of dilute (10 mM) equimolar zinc nitrate / hexamethylenetetramine solution is then held at 90 °C and run to depletion; the declining supersaturation of the depleting bath produces the tapered tips without any post-growth acid treatment.

**Target geometry (per crystal):** base 70–120 nm (measured across the hexagonal flats), height < 300 nm, tapered to a point, densely packed, c-axis vertical.

**Substrate:** zinc foil, **0.15 mm thick**, cut as a **⌀156 round blank** (the downstream etch/plate/strip flow defines a ⌀130 active area inside a 13 mm handling rim, to back a 150 mm silicon wafer). Mounted in a carrier that masks the reverse face so growth occurs on one side only.

---

## 2. Definitions and interpretation

- **"Acid etch" (post-growth)** — the tip-sharpening step applied *after* growth — is deliberately omitted here; taper is obtained from bath depletion alone.
- **Light etch (pre-growth)** — a brief, separate dilute-**acetic-acid** dip *before* growth (§6.2) that strips the native oxide and presents a fresh surface. It is retained, and is **not** the same step as the omitted post-growth etch. (Rev 2.0: acetic acid replaces dilute HCl — ZnO dissolves readily in weak organic acids, and the milder acid is gentler on the foil and eliminates HCl vapour handling. Rev 3.0: with the seed layer added, the etch's role is surface preparation for seeding; nucleation density is now set primarily by the seed layer.)
- **ZnO seed layer (pre-growth)** — a coat of ~5–10 nm ZnO nanocrystals formed by flood-coating the cleaned foil with dilute zinc acetate in ethanol and annealing at ~300 °C (§6.3). The seeds carry a (0001)-up texture, so rods nucleate dense, uniform, and c-axis vertical regardless of the foil's grain orientations. **Because ZnO dissolves in weak acids, no acid may contact the foil after the seed layer is applied.** *Naming:* always write "ZnO seed layer" for this step — the *silver seeding* of ZnO-SOP-020 (catalytic seed for electroless Ni-P) is a different step, and the two must stay unambiguous across the document set.
- **Depletion run:** running the fresh bath until the zinc precursor is spent and no fresh precipitate forms. A single, un-replenished charge self-limits rod height, which is how sub-300 nm height is held.
- **Base diameter:** dimensions are stated face-to-face (across flats). Across corners is ~1.155× larger; fix the across-flats convention for all SEM measurements.

---

## 3. Health, safety and environment

Consult the SDS for each reagent before starting. Key hazards:

- **Hexamethylenetetramine (HMTA)** — flammable solid; on heating in water it releases formaldehyde and ammonia. Weigh and run in a fume hood.
- **Zinc nitrate hexahydrate** — oxidiser; skin/eye/respiratory irritant. Keep away from combustibles.
- **Dilute acetic acid** (light-etch dip, ~2–5 % v/v) — irritant to eyes and skin at working strength; pungent vapour. Gloves and goggles. The **glacial acetic acid concentrate** used to make dilutions is corrosive and combustible — dilute in a fume hood, and always add acid to water, never water to acid.
- **Hot solution** — the 90 °C aqueous bath is a burn/scald hazard. Use a loosely covered (vented) vessel; never seal a hot bath and keep ≤ 95 °C to avoid pressure build-up.
- **Absolute ethanol** (seed solution and inter-coat rinse) — highly flammable liquid and vapour. Keep away from the hot hotplate and all ignition sources; work with small volumes; cap containers. Complete all ethanol steps and let the face dry **before** the anneal heat-up.
- **Zinc acetate dihydrate** — eye/skin irritant; zinc-bearing (heavy-metal waste stream).
- **Seed anneal (~300 °C)** — severe burn hazard; the foil and anneal plate stay hot long after heating stops. Handle with tongs and allow full cool-down before touching.
- **PPE:** nitrile gloves, safety goggles, lab coat; all HMTA weighing and bath heating in a fume hood.
- **Waste:** the spent bath carries dissolved and particulate zinc. Collect as aqueous heavy-metal waste; do not pour to drain. Neutralise/dispose per local regulations. Spent etch dip carries dissolved zinc acetate — same heavy-metal stream.

---

## 4. Materials, reagents and equipment

### 4.1 Reagents

- Zinc nitrate hexahydrate, Zn(NO₃)₂·6H₂O, ACS grade (M = 297.48 g/mol).
- Hexamethylenetetramine (HMTA), C₆H₁₂N₄, ≥ 99 % (M = 140.19 g/mol).
- Deionised water, Type I/II (≥ 18 MΩ·cm preferred), for bath make-up and rinsing.
- Acetone and isopropanol (IPA), reagent grade, for degreasing.
- Dilute acetic acid, ~2–5 % v/v (≈ 0.35–0.9 M), for the pre-growth light etch; dilute from glacial acetic acid (≥ 99 %) with DI water.
- Zinc acetate dihydrate, Zn(CH₃COO)₂·2H₂O, ACS grade (M = 219.51 g/mol), for the seed solution.
- Absolute ethanol (≥ 99.5 %), for seed-solution make-up and the inter-coat rinse.
- Dry nitrogen (or clean, oil-free compressed air) for drying.

### 4.2 Equipment

- Hotplate or water/oil bath, stable to 90 ± 2 °C, with a calibrated thermometer/thermocouple in the bath.
- Wide inert growth vessel (borosilicate crystallising dish or PP container) able to submerge the ⌀156 foil (round/square, ~⌀210 or 210 mm), with a loose lid/watch-glass cover.
- Substrate carrier that masks the reverse face and holds the foil face-down or tilted 15–45°.
- Hotplate capable of **300 ± 25 °C** for the seed anneal (the growth hotplate may serve if it reaches temperature), with a flat aluminium anneal plate larger than the ⌀156 blank; tongs.
- Pipette (~5 mL) and ethanol wash bottle for the seed coats; a clean, level surface for coating.
- Analytical balance (0.1 mg), volumetric glassware, PTFE-tipped tweezers, timer, sonicator, drying stand.

---

## 5. Bath specification

| Parameter | Specification | Notes / tolerance |
|---|---|---|
| Chemistry | Zn(NO₃)₂·6H₂O + HMTA, equimolar | 1 : 1 molar ratio |
| Concentration | 10 mM each | Dilute — thin bases, low per-rod budget |
| Solvent | Type I/II DI water | ≥ 18 MΩ·cm preferred |
| Zn(NO₃)₂·6H₂O loading | 2.975 g per litre | = 0.010 mol/L × 297.48 g/mol |
| HMTA loading | 1.402 g per litre | = 0.010 mol/L × 140.19 g/mol |
| As-mixed pH | ~5.5–6.5 | Do not adjust; not externally buffered |
| Temperature | 90 °C | Acceptable 88–92 °C; never seal, ≤ 95 °C |
| Agitation | Static (no stirring) | Convection re-feeds supersaturation and blunts tips |
| Charge | Single, un-replenished | Defines zinc budget → self-limited height |
| Run mode | Run to depletion | End when solution clears / no fresh precipitate |
| Typical run time | ~45–90 min | **Calibrate on first run;** record actual time |
| Substrate orientation | Face-down or tilted | Lets homogeneous particles fall clear of the face |

### 5.1 Reagent quantities by bath volume

| Bath volume | Zn(NO₃)₂·6H₂O | HMTA |
|---|---|---|
| 0.5 L | 1.487 g | 0.701 g |
| 1.0 L | 2.975 g | 1.402 g |
| 1.5 L | 4.462 g | 2.103 g |

**Sizing:** use the smallest volume that fully submerges the foil with ~10–20 mm clearance. A ⌀156 coupon face-down in a wide dish typically needs ~1.0–1.5 L (round/square vessel ~⌀210 or 210 mm). Scale masses linearly: mass = (value per L) × volume in L.

### 5.2 Seed solution specification

| Parameter | Specification | Notes / tolerance |
|---|---|---|
| Chemistry | Zn(CH₃COO)₂·2H₂O in absolute ethanol | Seed coat only — never enters the growth bath |
| Concentration | 5 mM | **0.110 g per 100 mL** ethanol |
| Make-up | Dissolve with brief sonication or mild warming (< 40 °C) | Must be fully clear before use |
| Coats | 3–5 flood coats | Each: flood 10–20 s → ethanol rinse → N₂ dry (§6.3) |
| Anneal | 300 ± 25 °C, 20–30 min, in air | Decomposes acetate to ~5–10 nm ZnO seeds, (0001)-up texture |
| Shelf life | ≤ ~1 week, sealed | Make fresh preferred; discard if hazy (slow hydrolysis) |

---

## 6. Procedure

### 6.1 Blank the round substrate

Cut the **⌀156 round zinc blank** from 0.15 mm zinc foil stock **before** any cleaning. The cut sits 13 mm outside the ⌀130 active zone, so it never touches the nanostructured area, and the rim it forms is sacrificial (dissolved at the ZnO-SOP-050 de-rim) — so edge finish is uncritical. The one spec that matters is that the blank drops cleanly into the carriers' **⌀156.3 locating pocket** (ZnO-DR-003/005).

1. **Method (in order of preference):**
   - **Custom ⌀156 steel-rule die** — press with an arbor press (or a mallet); ideal for thin, soft zinc at an exact arbitrary diameter. Preferred for repeatable batches.
   - **Adjustable rotary circle cutter** — set to 78 mm radius on a backing mat; no tooling, any radius, but hand-guided so verify roundness/diameter.
   - **Custom ⌀156 hollow / arch punch** — most robust; press-driven.
   - *(Laser is acceptable but zinc fume needs extraction.)* **Do not use the CNC router** — it deflects and grabs 0.15 mm foil and throws swarf.
2. **Backing:** cut over end-grain wood, a poly cutting board, or a self-healing mat so the blade fully severs the foil without tearing.
3. **Burr:** orient the tool so any burr lands on the **rim** (the sacrificial, de-rimmed side); knock down a burr that would keep the blank from seating.
4. **Fit check:** confirm the blank is round and drops flush into the ⌀156.3 carrier pocket; deburr or retrim if proud.
5. Handle by the rim only; keep the future growth face clean.

### 6.2 Substrate preparation — before-growth cleaning

1. Handle the foil only with PTFE-tipped tweezers by an edge; never touch the growth face.
2. Sonicate 5 min in acetone.
3. Sonicate 5 min in fresh isopropanol.
4. Sonicate 5 min in DI water to remove solvent residue.
5. **Light etch:** dip 15–30 s in dilute acetic acid (~2–5 % v/v) to strip the native oxide and open nucleation sites. The organic acid etches more slowly than the HCl it replaces, so the dip is longer — **calibrate the time on the first run** and keep it a controlled parameter; over-etching still thins and roughens the foil.
6. **Immediately** rinse under copious flowing DI water to stop the etch; do not let the freshly etched surface sit in air.
7. Blow dry at once with N₂ (or clean air), sheeting water off the face to avoid spots.
8. Proceed **immediately** to the seed-layer coat (§6.3); do not let the freshly etched surface sit in air. (Carrier mounting now happens after the seed anneal — §6.3 step 8.)

> **Note — light etch (Rev 2.0, role updated Rev 3.0).** Removing the passivating native oxide presents a fresh, wettable surface for the seed coat; the post-growth tip-sharpening etch remains omitted. Acetic acid replaces the former dilute HCl at equivalent function but lower corrosivity and no acid vapour hazard; ZnO dissolves readily in weak organic acids — which is also why **no acid may touch the foil after §6.3**. With the seed layer now setting nucleation density, over-etching gains nothing: hold to the short end of the dip window unless wetting is visibly poor.

### 6.3 ZnO seed layer (coat and anneal)

Rolled zinc foil is polycrystalline with random grain orientations; rods nucleating directly on bare foil inherit that spread and grow at scattered tilts. This step lays down a dense, uniform template of ~5–10 nm ZnO nanocrystals with (0001)-up texture, so the rods grow c-axis vertical with a tight base-diameter distribution, independent of the grains beneath. Dense, uniform nucleation also self-corrects residual tilt: off-vertical rods run into neighbours and terminate while vertical rods win.

**No acid contact from this point on — the acetic dip dissolves ZnO seeds.**

1. Perform §6.2 in full (degrease, light etch, rinse, dry) and continue directly — do not pause between etch and first coat.
2. Lay the foil flat, growth face up, on a clean, level surface.
3. Flood the growth face with seed solution (§5.2) from a pipette — **~3–5 mL for the ⌀156 face**, enough to wet edge to edge. Let stand 10–20 s.
4. Rinse gently with clean absolute ethanol from a wash bottle, then blow dry with N₂, sheeting toward the rim. The rinse is what leaves a sparse adsorbed layer rather than drying rings — **do not skip it.**
5. Repeat steps 3–4 for a total of **3–5 coats**.
6. **Anneal:** lay the foil dead flat on the aluminium anneal plate, growth face up (weight the rim with a flat ring if it lifts), ramp gently to **300 ± 25 °C**, hold **20–30 min** in air, then cool slowly in place. This decomposes the acetate to ZnO seed crystals. Stay far below zinc's 419.5 °C melting point. The face dulls slightly from thermal oxide — acceptable; the entire Zn/ZnO template dissolves at ZnO-SOP-040.
7. *Optional density lever (qualify before adopting):* repeat the full coat-set + anneal cycle a second time for denser seeding.
8. Mount in the carrier (reverse face masked) and proceed to bath preparation and growth promptly. The anneal fully softens the zinc — the foil comes off the plate flatter but floppier; handle by the rim with full support.

### 6.4 Bath preparation

1. Charge the vessel with ~90 % of the target DI water volume.
2. Weigh Zn(NO₃)₂·6H₂O and HMTA to the quantities in §5.1; record actual masses.
3. Dissolve the zinc nitrate fully with gentle stirring, then dissolve the HMTA; stir until completely clear.
4. Make up to final volume with DI water. Optionally filter (0.2 µm) to remove stray particulates.
5. Cover and pre-heat the solution to 90 °C. Confirm with the in-bath probe before loading the substrate.

### 6.5 Growth run (to depletion)

1. Immerse the carried substrate, growth face down or tilted, into the 90 °C bath. Start the timer (t₀). Ensure no air bubbles are trapped on the face.
2. Hold at 90 °C, static and loosely covered. Do not stir, agitate, or replenish the bath.
3. Let the run proceed to depletion: the solution turns milky at peak nucleation, then clears as zinc is consumed. Endpoint = a clear (or markedly clarified) bath with no fresh precipitate forming.
4. Record the actual depletion time (expect ~45–90 min on the first calibration run) and the bath temperature profile.

### 6.6 Recovery — after-growth cleaning

1. At the endpoint, withdraw the substrate promptly.
2. Immediately rinse under copious flowing DI water to quench the reaction and float off loosely bound homogeneous particles. Do not wipe or brush the surface.
3. Optional, if loose powder persists: a few seconds of very gentle low-power DI sonication. **Caution** — aggressive sonication dislodges rods; use sparingly and inspect afterward.
4. Blow dry with N₂, holding the foil so water sheets off cleanly; avoid drying spots.
5. Optional consolidation dry: up to ~150–250 °C in air to drive off residual water (gentle ramp — the 0.15 mm foil is stiffer and less warp-prone than the old 70 µm stock, but still ramp gently; stay far below the 419.5 °C zinc melting point). Not required for geometry.
6. Store the finished foil flat in a clean, dry, covered container.

---

## 7. Acceptance criteria and QC

- **Seed layer (post-anneal, pre-growth):** uniform faint tint change across the face; no rings, droplet marks, streaks, or bare patches. Rings or patches → re-clean and re-seed before committing the growth run.
- **Visual (post-growth):** uniform matte white/grey coating over the growth face; no bare patches, no thick powdery cake.
- **SEM (plan + cross-section) — base** (across flats) 70–120 nm; height < 300 nm; tips tapered to a point; densely packed without coalescing into a film; rods c-axis vertical and parallel in cross-section (tilt spread tight — the seeded array should not show splayed rods).
- **Process:** spent bath clear at pull; depletion time logged.
- **Rev 3.0 first-run gate:** the seed layer splits the same 10 mM single charge across more rods, so expect **denser, shorter, thinner** output than the Rev 2.x expectation. Re-calibrate base diameter, height, packing, and verticality by SEM on the first seeded run before releasing the recipe to routine use.

**Expected first-pass output (10 mM depletion, seeded):** trends denser, shorter, and thinner-based than the unseeded Rev 2.x expectation (base ~60–100 nm, height ~250–380 nm, strong taper) — treat those numbers as the upper envelope and let the first seeded run set the new baseline. If height still edges over 300 nm, reduce concentration toward ~8 mM (which depletes sooner and shorter) and re-qualify; if bases fall well under 70 nm, drop to 3 coats.

---

## 8. Troubleshooting

| Observation | Likely cause → corrective action |
|---|---|
| Height > 300 nm | Per-rod zinc budget too high → dilute toward 8 mM; confirm single charge; optionally drop to 88 °C. |
| Bases > 120 nm / merging | Too much lateral growth → lower concentration; verify not double-charged. |
| Bases < 70 nm / sparse | Weak nucleation → add seed coats (3 → 5) or a second coat-set + anneal cycle; verify the anneal reached ≥ ~275 °C (acetate does not fully decompose below that); improve degrease; transfer promptly between steps. |
| Rods tilted / splayed | Seed coat thin or patchy (foil grains showing through) → add coats or a second coat-set + anneal cycle; confirm the ethanol rinse after **every** coat; confirm no acid contact after seeding. |
| Rings / streaks in the array | Seed solution allowed to dry unrinsed → rinse with clean ethanol after every coat; level the foil during coating; discard hazy seed solution. |
| Blunt / flat tips | Bath not truly depleted, or convection re-fed it → confirm run to clear; keep strictly static. |
| Loose powdery deposit | Excess homogeneous nucleation settling on the face → keep face-down; filter make-up; gentler heat-up. |
| Patchy / non-uniform film | Residual oxide, contamination, or trapped bubbles → re-clean and re-etch; ensure the face wets fully on immersion. |
| Foil thinned / warped / pitted | Light etch too long or acid too concentrated → shorten the dip; dilute the acid; rinse promptly. |
| Rods detached after rinse | Recovery too aggressive → gentler DI rinse; reduce or eliminate sonication. |

---

## 9. Waste and storage

- Collect spent baths and zinc-bearing rinse water (including the spent acetic etch, now zinc acetate solution) as aqueous heavy-metal waste; neutralise and dispose per local regulations. Do not drain-dispose.
- Spent seed solution and inter-coat ethanol rinses are **zinc-bearing flammable organic waste** — collect separately from the aqueous stream; do not drain-dispose.
- Store unused reagents dry and sealed; HMTA away from heat and ignition; zinc nitrate away from combustibles; glacial acetic acid away from oxidisers and bases; ethanol away from ignition sources; zinc acetate dry.
- Store finished substrates flat, dry, covered, and labelled with run ID and depletion time.

---

## 10. Revision history

| Rev | Date | Author | Change summary |
|---|---|---|---|
| 1.0 | __________ | ____________ | Initial release — 10 mM depletion run; pre-growth light etch (dilute HCl) included, post-growth acid etch omitted. |
| 2.0 | __________ | ____________ | Lower-toxicity substitution: pre-growth light etch changed from dilute HCl to dilute acetic acid (~2–5 % v/v); dip lengthened to 15–30 s with first-run calibration and nucleation-density re-verification gate. |
| 2.1 | __________ | Croft Swonyoung | Substrate updated to **0.15 mm zinc foil, ⌀156 round blank** (was 70 µm × 100×125) for the round wafer-scale set (backs a 150 mm Si wafer per ZnO-SOP-050 Rev 4.0); growth-vessel sizing (~1.0–1.5 L, ⌀210 class) and foil warp/etch notes updated. Growth chemistry, bath spec, and target tip geometry unchanged. |
| 2.2 | __________ | Croft Swonyoung | Added §6.1 blanking method for the ⌀156 round substrate (custom steel-rule die preferred; rotary cutter / hollow punch alternatives; router prohibited for foil); burr-to-rim and ⌀156.3 pocket-fit notes. Subsections §6.1–6.4 renumbered to §6.2–6.5. |
| 3.0 | __________ | Croft Swonyoung | Added the **ZnO seed layer** (new §6.3): 5 mM zinc acetate dihydrate in absolute ethanol, 3–5 flood coats with ethanol rinse each, annealed 300 ± 25 °C / 20–30 min in air — decouples rod orientation from foil grain orientation for a c-axis-vertical, tight-distribution array. Title changed from *Self-Seeded* to *Seeded*. Light etch retained as surface prep; **no acid contact after seeding** (ZnO dissolves in weak acids). Carrier mounting moved to after the seed anneal; §6.3–6.5 renumbered §6.4–6.6; seed-solution spec added as §5.2; reagents, equipment, HSE, QC (seed-tint check; Rev 3.0 recalibration gate — seeded runs trend denser/shorter/thinner), troubleshooting, and waste updated. Naming rule: "ZnO seed layer" here vs. "silver seeding" in ZnO-SOP-020. |

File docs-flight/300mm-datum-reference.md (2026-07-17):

<!-- Public Domain Dedication: CC0 1.0 Universal -->
> **Public Domain · CC0 1.0 Universal.** Author: **Croft Swonyoung**. To the extent possible under law, the author has waived all copyright and related or neighbouring rights to this document and dedicates it to the public domain worldwide (CC0 1.0). No warranty. See `LICENSE` or <https://creativecommons.org/publicdomain/zero/1.0/>.
>
> Part of the *ZnO nanovoid process* document set (300 mm flying line). Verify file integrity against `CHECKSUMS.sha256`.

---

# Master Datum — 300 mm flying-machine line

**The single source of truth for every dimension in the `docs-flight/` line.** All
300 mm SOPs, design references, and DXF cut files must cite these numbers, not
restate their own. Derived from the 150 mm line (`../docs-rotor/`) by scaling the
wafer ⌀150 → ⌀300; the **chemistry is identical**, only geometry, tooling, and
mass change.

**Status:** proposed defaults, ready to build against. Items still needing maker
sign-off are marked **[confirm]**; the rest are locked.

## 1. Core stack datum

| Parameter | 150 mm (reference) | **300 mm (this line)** | Note |
|---|---|---|---|
| Wafer diameter | ⌀150.0 | **⌀300.0** | — |
| Wafer thickness | 0.675 mm | **0.775 mm** | SEMI standard for 300 mm — **locked** |
| Wafer finish | 1-side polished | **1-side polished** | polished face is the working cap |
| Active (etched) region | ⌀130 | **⌀280** | 10 mm wafer margin (same absolute as 150 mm) |
| Zinc foil thickness | 0.15 mm | **0.15 mm** | template thickness is wafer-independent |
| Zinc handling rim | 13 mm | **13 mm** | per side |
| Zinc blank | ⌀156 | **⌀306** | = active ⌀280 + 2 × 13 mm rim |
| Ni-P thickness | 25 µm | **25 µm** | diameter-independent |
| Per-cell pitch | ≈0.78 mm | **≈0.875 mm** | wafer 0.775 + Ni-P 0.025 + bond ~0.075 |

## 2. Mass (flyer-critical)

| Item | Value | Basis |
|---|---|---|
| Silicon wafer | ≈128 g | ⌀300 × 0.775 mm, ρ 2.33 g/cm³ |
| Ni-P layer | ≈12 g | ⌀280 active × 25 µm, ρ ~7.9 g/cm³ |
| Silicone bond | ≈5 g | ⌀280 × ~75 µm, ρ ~1.1 g/cm³ |
| **Per cell** | **≈145 g** | — |
| Stack (N cells) | **≈0.145 N kg** active | + platens + envelope/getter |

> **Scaling caveat (record in the flyer spec):** active area (~4.6×) and cell mass
> (~4.4×) scale together vs 150 mm, so **thrust-to-weight is ~scale-invariant.**
> The reason for choosing 300 mm is **handling / throughput** — fewer, larger parts
> to process, bond, and stack for a given total active area — **not** a better lift
> ratio. State this plainly wherever lift is discussed.

## 3. Carrier / cut-set datum (bounded by the 500 × 600 mm bed)

The shared carrier plate is the largest cut part and sets the bed size. Scaled
from the 150 mm carrier (window ⌀130 · O-ring ⌀143 · pocket ⌀156.3 · bolt circle
⌀174 ×12 M4 · outer ⌀190), keeping the seal/land widths roughly constant:

| Feature | **300 mm value** | Note |
|---|---|---|
| Window (active aperture) | ⌀280 | exposes the ⌀280 active region |
| O-ring groove | ⌀296 | seals around the active area, inside the coupon |
| Coupon pocket | ⌀306.3 × 0.15 mm deep | locates the ⌀306 zinc blank |
| Bolt circle | ⌀330, **×16 M4** | more bolts than the 150 mm ×12 for seal/flatness — **locked** |
| Carrier outer | **⌀350** | fits the 500 × 600 bed with clamp margin |

- **Bed:** standard **500 × 600 mm** router. ⌀350 part + ~50 mm workholding each
  side ≈ ⌀450 blank → fits (use the 600 mm axis for clamp length). ~1 carrier per
  sheet, as on the 150 mm line.
- **Companion plastic parts** (strip backer, clamp frame, immersion/seeding
  carrier) scale to the ⌀306 coupon; all cut on the same 500 × 600 router.
- **Aluminium wafer chuck** (⌀300+): heavier cut; **no waterjet** (cost) → rigid
  mill, slow router pass, outsource, or an alternative flat material. Decide when
  the chuck is designed (plan §5.1).

## 4. What scales with area (not diameter)

For sizing baths, getters, and process times, the driver is **area (~4×)**, not
thickness:
- Bath / reagent volumes ~4× (SOP-010/020/030/040): larger vessels, longer fill.
- Strip H₂/zincate load ~4× (SOP-040); the ~10–12 h void-clearing is
  void-geometry-limited (unchanged).
- Getter capacity ~4× the permeation/outgassing area (SOP-060).
- Vacuum envelope + chamber-sealer clearance sized for ⌀300+.

## 5. Naming and rationale (decided 2026-07-15)

- **File naming:** reuse the 150 mm step numbers with a **`-300` suffix** —
  `ZnO-SOP-010-300`, `ZnO-DR-001-300`, `ZnO_cut_<part>_300.dxf`, `ZnO-SP-001-300`.
  The flying-integration SOP is `ZnO-SOP-080-300`.
- **300 mm rationale:** **handling / throughput** (fewer, larger parts per unit
  active area). T/W is ~scale-invariant — the win is process/assembly efficiency,
  not lift ratio.

**All datum items locked (confirmed 2026-07-15):** wafer thickness **0.775 mm** and
carrier bolt pattern **⌀330 ×16 M4** are final, along with everything above. Ready
to build against.

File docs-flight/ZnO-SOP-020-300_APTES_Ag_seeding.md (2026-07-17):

<!-- Public Domain Dedication: CC0 1.0 Universal -->
> **Public Domain · CC0 1.0 Universal.** Author: **Croft Swonyoung**. To the extent possible under law, the author has waived all copyright and related or neighbouring rights to this document and dedicates it to the public domain worldwide (CC0 1.0). No warranty. See `LICENSE` or <https://creativecommons.org/publicdomain/zero/1.0/>.
>
> Part of the *ZnO nanovoid process* document set (300 mm flying line). Verify file integrity against `CHECKSUMS.sha256`.

---

> **300 mm line · derived from the 150 mm `ZnO-SOP-020` Rev 2.1.** The seeding
> **chemistry, temperatures, per-litre concentrations, and target seed geometry are
> identical** to the 150 mm procedure — only the **substrate blank, vessels/chambers,
> fixtures, reagent volumes, and per-coupon masses** scale with the larger wafer. All
> dimensions come from `300mm-datum-reference.md`; this SOP does not restate them
> independently.

---

# Working Procedure & Specification

## APTES Functionalisation and Silver Seeding of ZnO Nanotips (300 mm)
### AgNO₃ activation with ascorbate reduction — catalytic seed layer for electroless Ni-P

| Field | Value | Field | Value |
|---|---|---|---|
| Document no. | ZnO-SOP-020-300 | Revision | 1.0 |
| Effective date | ____________ | Supersedes | — (new; derived from 150 mm Rev 2.1) |
| Author | Croft Swonyoung | Approved by | ____________ |
| Predecessor step | ZnO-SOP-010-300 (nanotip growth) | Next step | ZnO-SOP-030-300 (electroless Ni-P) |

---

## 1. Purpose and scope

This procedure functionalises grown ZnO nanotips with an aminosilane (APTES) monolayer, then anchors and reduces silver to form a dispersed layer of metallic Ag⁰ nanoparticles. That silver layer is the catalytic seed that initiates a subsequent electroless nickel-phosphorus (Ni-P) deposition; it is **not** the final metallisation.

**Process chain:** hydroxylate → vapour-phase APTES (amine groups) → AgNO₃ loading (Ag⁺ capture) → ascorbate reduction (Ag⁰ seeds) → hold under N₂ → electroless Ni-P (ZnO-SOP-030-300).

**Substrate:** Zn foil, **0.15 mm × ⌀306 round blank** (⌀280 active area inside a 13 mm rim, to back a 300 mm silicon wafer — see `300mm-datum-reference.md`), bearing ZnO nanotips on one face (reverse masked by the carrier), from ZnO-SOP-010-300.

**Design intent:** amine density sets seed density sets Ni-P nucleation density, so silane quality carries the "densely packed" goal into the metal layer. *(At 300 mm the same requirement now has to hold uniformly across the larger ⌀280 field — see §7.)*

---

## 2. Definitions and interpretation

- **Seeding / activation:** creating catalytic Ag⁰ nuclei on the surface. Ni-P will not initiate on bare ZnO/APTES; it needs the reduced metallic silver.
- **Vapour-phase silanisation:** APTES is delivered as vapour to a substrate in a sealed chamber, not by liquid immersion. Chosen here because it coats the high-aspect-ratio tip array evenly and avoids silane polymerising in the crevices between tips. *(Even delivery over the larger ⌀280 face is a new concern at 300 mm — see §6.2 and §7.)*
- **Near-neutral rule:** the substrate (ZnO tips on Zn foil) is amphoteric and Zn is very active. **Keep every wet step near-neutral pH.** No ammonia, no strongly alkaline reductants, no strong acid.
- **Reductant — sodium ascorbate (from 150 mm Rev 2.0).** Ascorbate reduces Ag⁺ → Ag⁰ at room temperature and is essentially benign, replacing dimethylamine borane (toxic; borane off-gassing in the box). Use the **sodium salt**, or free ascorbic acid neutralised to pH 6–7: free ascorbic acid at working strength sits near pH 3, which would violate the near-neutral rule. Ascorbate is a milder reducer than DMAB — expect **minutes rather than seconds** to the grey haze, and re-qualify seed size/dispersion on the first run.
- **Silver source:** AgNO₃ (soluble, gives free Ag⁺ that the amine can coordinate). AgCl was considered and rejected — it is essentially insoluble and the complexants needed to dissolve it either attack the substrate (ammonia) or out-compete the amine anchoring (thiosulfate).

---

## 3. Health, safety and environment

Consult the SDS for each reagent before starting. Key hazards:

- **APTES** — moisture-sensitive, corrosive/irritant, flammable liquid. Handle dry, in a glovebox or hood; gloves and goggles.
- **Silver nitrate (AgNO₃)** — oxidiser; corrosive, causes burns and black staining of skin; light-sensitive; toxic to aquatic life. See §3.1 for the substrate-specific galvanic hazard.
- **Sodium ascorbate / ascorbic acid** — low hazard (food-grade antioxidant); mild eye/respiratory irritant as dust. No flammable off-gassing — the special glovebox purge provisions required for the former borane reductant no longer apply.
- **Enclosed-atmosphere work** — silver stages need dim/amber light (silver photoreduces).
- **Larger reagent volumes** — the silver and reductant baths are now **~4× larger (~4× the 150 mm volume)** to submerge the ⌀306 coupon. More silver in solution per batch means a larger silver-recovery burden and a larger spill footprint; use stable, well-supported vessels and handle the fuller baths with safe lifting practice.
- **PPE:** nitrile gloves, safety goggles, lab coat.
- **Waste:** collect silver-bearing solutions and rinses separately for silver recovery; do not drain-dispose (volumes are now ~4× the 150 mm line — size the recovery stream accordingly). Never mix silver solution with ammonia (explosive silver-nitride/fulminate risk).

### 3.1 Substrate-specific hazard — galvanic silver displacement

Any **bare zinc** contacting AgNO₃ will spontaneously cement silver and dissolve zinc (Zn + 2 Ag⁺ → Zn²⁺ + 2 Ag). This roughens and undercuts the substrate during silver loading, not just during later plating. Mitigate by keeping the reverse face masked, minding cut edges, keeping AgNO₃ concentration modest and immersion short, and ensuring continuous ZnO/APTES coverage so solution cannot reach foil through pinholes. *(The ⌀306 coupon has a longer rim/edge perimeter to mask and inspect than the 150 mm blank — check the whole circumference.)*

---

## 4. Materials, reagents and equipment

### 4.1 Reagents

- (3-Aminopropyl)triethoxysilane (APTES), C₉H₂₃NO₃Si (M = 221.37 g/mol), anhydrous grade.
- Silver nitrate (AgNO₃), ACS grade (M = 169.87 g/mol).
- Sodium L-ascorbate, C₆H₇NaO₆ (M = 198.11 g/mol) — or L-ascorbic acid, C₆H₈O₆ (M = 176.12 g/mol), neutralised to pH 6–7 with dilute NaOH at make-up.
- Deionised water, Type I (≥ 18 MΩ·cm).
- Anhydrous ethanol (optional silver-bath co-solvent and rinsing).
- Dry nitrogen (glovebox atmosphere and drying).

### 4.2 Equipment

- UV-ozone cleaner or low-power O₂ plasma unit (outside the glovebox), **with a working area / chamber that clears the ⌀306 coupon** (⌀280 active field must be exposed evenly — a source too small for the face will hydroxylate non-uniformly; see §6.1 / §7).
- Wet-type N₂ glovebox with amber / low-light capability, large enough to work the ⌀306 coupon and the larger vessels comfortably.
- Sealed vapour chamber (glass desiccator or closed vessel) **sized to accept the ⌀306 coupon** for APTES vapour deposition; small inert reservoir dish for the APTES liquid.
- Hotplate capable of a stable ~110 °C cure (gentle ramp), platen large enough to support the full ⌀306 disc flat.
- Amber glassware, PTFE-tipped tweezers, analytical balance (0.1 mg), timer, drying stand, pH paper/meter (reductant make-up check).
- Substrate carrier (round, per ZnO-DR-003-300 / ZnO-DR-005-300) that masks the reverse face and holds the **⌀306** coupon flat; amber wet-seeding vessels sized to submerge the ⌀306 coupon with clearance (~⌀340–360 mm, ~4× the 150 mm bath volume). The larger coupon is floppier — support it fully across all transfers (see §6).

---

## 5. Process specification

| Stage | Parameter | Specification | Notes / tolerance |
|---|---|---|---|
| Hydroxylation | Method | UV-ozone 10–15 min *or* O₂ plasma 30–60 s (low power) | Maximises surface –OH; leaves trace surface water (needed for vapour APTES); ensure the source covers the whole ⌀280 field |
| Hydroxylation | Location | Outside the box | Transfer into the box promptly; do not over-dry |
| APTES vapour | Reservoir | ~800–1200 µL liquid APTES, not touching samples | Scaled ~4× with the larger chamber headspace/face; sealed chamber |
| APTES vapour | Condition | ~70 °C, 45–60 min (optional mild vacuum) | RT overnight is an alternative; larger chamber may need the longer end of the window / mild vacuum for even vapour reach |
| APTES cure | Condition | ~110 °C, 20–30 min, air or N₂ | Gentle ramp; far below 419.5 °C Zn m.p. |
| Ag loading | Solution | 10–20 mM AgNO₃ in DI (or 1:1 ethanol/water) | Ethanol/water wets the array better; **per-litre loading unchanged** |
| Ag loading | Condition | RT, 15–30 min, dim/amber light | Brief gentle DI rinse after |
| Reduction | Solution | 10–50 mM sodium ascorbate, aqueous, pH 6–7 | Fresh; make up immediately before use; discard if yellowed; **per-litre loading unchanged** |
| Reduction | Condition | RT, ~2–10 min to a faint grey haze | Milder than the former DMAB — allow minutes; rinse DI, blow dry N₂ |
| All wet stages | pH | Near-neutral | Substrate is amphoteric — see §2; verify reductant pH at make-up |
| Silver stages | Light | Dim / amber | AgNO₃ and Ag⁺ photoreduce |
| Post-reduction | Storage | Hold under N₂ until plating | Keeps fresh silver clean |

> **Concentrations, temperatures, and times are unchanged from the 150 mm line** — they
> are per-litre / per-area effects independent of coupon size. The ⌀306 coupon simply
> needs **~4× the litres** of the same solutions in larger vessels; only volume-driven
> fill and immersion handling scale. The APTES reservoir scales with the larger chamber
> headspace, not the bath concentration (APTES is vapour-delivered, so it has no bath
> concentration).

### 5.1 Solution make-up (representative volumes)

Per-litre loadings are unchanged from the 150 mm line; only the batch volume grows (~4×) to submerge the ⌀306 coupon in the larger amber vessels. Columns below add the ~4× working volumes alongside the original reference columns.

| Solution | Target | Per 100 mL | Per 250 mL | Per 1.0 L | Per 2.0 L |
|---|---|---|---|---|---|
| AgNO₃ loading | 15 mM | 0.255 g | 0.637 g | 2.548 g | 5.096 g |
| AgNO₃ (low) | 10 mM | 0.170 g | 0.425 g | 1.699 g | 3.397 g |
| AgNO₃ (high) | 20 mM | 0.340 g | 0.849 g | 3.397 g | 6.795 g |
| Sodium ascorbate reductant | 30 mM | 0.594 g | 1.486 g | 5.943 g | 11.887 g |
| — as free ascorbic acid* | 30 mM | 0.528 g | 1.321 g | 5.284 g | 10.567 g |

\* If made from free ascorbic acid, neutralise to pH 6–7 with dilute NaOH before use and verify with pH paper/meter. **Scale linearly** — mass = (per-litre loading) × volume in L. **Sizing:** use the smallest volume that fully submerges the ⌀306 coupon in its carrier with clearance — typically **~1.5–2 L** per wet stage in a ~⌀340–360 mm amber vessel (vs. a few hundred mL at 150 mm). APTES is delivered as vapour, so it has no bath concentration — only the reservoir volume in §5 (~800–1200 µL, scaled with the larger chamber).

---

## 6. Procedure

> **Glovebox flow (one in, one out).** Hydroxylation (§6.1) happens outside, as it needs the UV-ozone / plasma tool. Run §6.2 through §6.5 as a single campaign inside the wet box: enter once with hydroxylated foil, exit once with plating-ready seeded tips. Keep amber light for the silver stages. **Support the large ⌀306 coupon fully on every transfer** — it is floppier than the 150 mm blank and must stay flat so the APTES layer and seed field come out uniform.

### 6.1 Surface hydroxylation (before the box)

1. Handle the foil only with PTFE-tipped tweezers by an edge; never touch the growth face. Support the full ⌀306 disc so it does not fold.
2. UV-ozone the growth face 10–15 min (or low-power O₂ plasma 30–60 s) to maximise surface –OH. **Ensure the source illuminates/treats the whole ⌀280 active field evenly** — if the tool's active area is smaller than the coupon, index the coupon or use a larger source, and confirm uniform activation (see §7). Uneven hydroxylation seeds uneven APTES and uneven silver downstream.
3. Do **not** bake bone-dry afterward — the trace adsorbed water is needed for the vapour silane to hydrolyse and bond. Transfer into the glovebox promptly.

### 6.2 Vapour-phase APTES silanisation (in the box)

1. Place the substrate in the sealed chamber (sized for the ⌀306 coupon) with a small open reservoir of ~800–1200 µL APTES nearby (scaled to the larger chamber headspace). Liquid APTES must not contact the sample. Seat the coupon flat on a support so the whole face is exposed to the vapour.
2. Hold ~45–60 min at ~70 °C (optionally under mild vacuum to speed vapour transport), or leave at RT overnight. **Over the larger face, favour the longer end of the window and/or mild vacuum** so vapour reaches the centre and edges alike.
3. Remove and cure at ~110 °C for 20–30 min to condense the siloxane bonds (gentle ramp; the 0.15 mm foil thickness is unchanged, but the larger ⌀306 disc has more unsupported area — cure it on a full-face support to keep it flat; still far below the 419.5 °C Zn m.p.).
4. Verify monolayer quality once before committing a batch (water contact-angle drop, or XPS nitrogen signal) — **and at 300 mm, sample the centre and edge of the ⌀280 field, not just one spot**, to confirm the silane is uniform across the larger area (see §7).

### 6.3 Silver loading — AgNO₃ (in the box, dim/amber light)

1. Immerse in 10–20 mM AgNO₃ (DI, or 1:1 ethanol/water for better array wetting), RT, 15–30 min, dark. Use the ~1.5–2 L working volume that submerges the ⌀306 coupon with clearance; **per-litre AgNO₃ loading is unchanged**. Enter the bath so no air is trapped against the larger face — tilt on entry to sweep bubbles clear.
2. Withdraw and give a brief gentle DI rinse to remove unbound silver.
3. Inspect edges and any exposed foil for dark cemented silver — that is galvanic displacement (§3.1) and indicates a masking or coverage problem, not successful seeding. **Check the whole ⌀306 circumference** — the longer edge perimeter is more chances for a masking gap.

### 6.4 Reduction to Ag⁰ seeds (in the box)

1. Make up fresh 10–50 mM sodium ascorbate (aqueous; or ascorbic acid neutralised to pH 6–7) immediately before use, in the ~1.5–2 L working volume (**per-litre loading unchanged**). Verify pH 6–7. Discard and remake if the solution has yellowed — that is oxidised ascorbate and it reduces poorly.
2. Immerse the silver-loaded substrate at RT. A faint silver-grey haze should develop within ~2–10 minutes as Ag⁺ → Ag⁰. Ascorbate is milder than the former DMAB — allow up to ~15 min before treating a slow run as a fault. **Watch that the haze develops evenly across the whole ⌀280 field**, not just at the centre or one edge.
3. Rinse in DI and blow dry with N₂, holding the ⌀306 disc so water sheets off cleanly.

### 6.5 Hold / handoff

1. Store the seeded substrates under N₂ in the box (or a sealed inert container) until the electroless Ni-P step, so the fresh silver stays clean. Store the large coupon flat between clean flat supports.
2. Label with run ID, silane batch, and seeding date.

---

## 7. Acceptance criteria and QC

- **APTES:** measurable contact-angle change vs. bare ZnO (or XPS N signal); uniform, with no visible polymer haze or particulate film. **Sample centre and edge of the ⌀280 field** — over the larger active area, confirm the silane is uniform, not just present at one spot (a bigger face is more prone to centre-to-edge gradients from uneven hydroxylation or vapour reach).
- **Silver seeds (SEM):** fine, evenly distributed Ag nanoparticles decorating the tips; dispersion (not a continuous film) is the goal. Sample **multiple sites across the ⌀280 field** (centre + several radii/edges), not just the centre — uniform Ag dispersion across the larger field is a first-run gate at 300 mm. **First-run gate:** re-qualify seed size and dispersion with the ascorbate reductant (its milder kinetics can shift the particle-size distribution) **and confirm cross-field uniformity** before releasing the recipe to routine use.
- **Substrate integrity (SEM):** ZnO tips intact — no dissolution, rounding, or roughening from a pH excursion; no cemented silver on the foil or edges (check the full ⌀306 circumference).
- **Readiness:** surface visibly activated (faint grey, even across the face) and held under N₂ pending plating.

---

## 8. Troubleshooting

| Observation | Likely cause → corrective action |
|---|---|
| No / patchy grey after reduction | Poor APTES monolayer, short Ag loading, or oxidised/stale ascorbate → re-hydroxylate and redo §6.2; extend loading; make fresh reductant and verify pH 6–7. |
| **Centre-to-edge non-uniformity of APTES or Ag seeds** (new at 300 mm) | Uneven hydroxylation or vapour reach over the larger ⌀280 face, or uneven immersion → cover the whole field in §6.1 (index or larger source); favour the longer vapour step / mild vacuum in §6.2; ensure even, bubble-free immersion depth in §6.3–6.4; sample multiple sites per §7. |
| Reduction very slow (> ~15 min) | Ascorbate weaker than expected → confirm fresh, un-yellowed solution; raise concentration within 10–50 mM; extend time. Do not substitute an alkaline reductant. |
| Dark silver on foil / edges; tips undercut | Galvanic displacement on bare Zn (§3.1) → improve masking; check ZnO/APTES pinhole coverage; shorten immersion; lower AgNO₃ concentration. Inspect the full ⌀306 edge — more perimeter to mask than at 150 mm. |
| Silane haze / particulate film | Too much moisture in the vapour step → drier box atmosphere, smaller reservoir, shorter time. |
| Tips dissolved / roughened | pH excursion → keep all wet steps near-neutral; verify the reductant was neutralised (free ascorbic acid is pH ~3 — always use the sodium salt or neutralise). |
| Uneven seed density | Vapour did not reach the whole array → use mild vacuum, extend the vapour step; confirm even hydroxylation. Over the ⌀280 field this is more likely — verify with centre + edge sampling. |
| Coupon folds / warps during handling | Larger ⌀306 coupon is floppier than the 150 mm blank → support the full disc on every transfer; seat it on a full-face support for the cure and dry; store flat between supports. |
| Seeds tarnish / discolour before plating | Air / contamination exposure → hold under N₂; shorten the gap to plating. |

---

## 9. Waste and storage

- Collect silver-bearing solutions and rinses separately for silver recovery; do not drain-dispose (volumes are ~4× the 150 mm line — size the recovery stream accordingly). Never combine with ammonia.
- Spent ascorbate solutions mixed with silver follow the silver-recovery stream; ascorbate itself carries no special disposal burden.
- Store APTES sealed and dry (moisture-sensitive); AgNO₃ in amber, away from light and organics; sodium ascorbate/ascorbic acid sealed, cool, and dry (oxidises slowly in air).
- Store seeded substrates under N₂, labelled, and flat between clean supports, until the electroless Ni-P step.

---

## 10. Revision history

| Rev | Date | Author | Change summary |
|---|---|---|---|
| 1.0 | __________ | Croft Swonyoung | **Initial release of the 300 mm flying-line variant, derived from the 150 mm `ZnO-SOP-020` Rev 2.1.** Substrate scaled to a **⌀306 round zinc blank** (⌀280 active + 13 mm rim, backing a 300 mm wafer per `300mm-datum-reference.md`); UV-ozone/plasma source, APTES vapour chamber, and wet-seeding vessels sized to clear the ⌀306 coupon; wet-bath working volumes ~4× (~1.5–2 L) with the §5.1 table extended to per-1 L/2 L columns; APTES reservoir scaled to ~800–1200 µL for the larger chamber; seeding carrier updated to ZnO-DR-003-300 / ZnO-DR-005-300 and cross-references updated to the -300 names; added centre-to-edge APTES/Ag uniformity checks (multi-site sampling across the ⌀280 field) and large-floppy-coupon handling/flatness notes. **Seeding chemistry, per-litre concentrations, temperatures, times, near-neutral rule, "no cemented Ag on edges," and glovebox/inert-atmosphere requirements are unchanged** — they are per-litre / per-area effects independent of coupon size. |

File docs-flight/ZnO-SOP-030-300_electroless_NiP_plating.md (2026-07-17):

<!-- Public Domain Dedication: CC0 1.0 Universal -->
> **Public Domain · CC0 1.0 Universal.** Author: **Croft Swonyoung**. To the extent possible under law, the author has waived all copyright and related or neighbouring rights to this document and dedicates it to the public domain worldwide (CC0 1.0). No warranty. See `LICENSE` or <https://creativecommons.org/publicdomain/zero/1.0/>.
>
> Part of the *ZnO nanovoid process* document set (300 mm flying line). Verify file integrity against `CHECKSUMS.sha256`.

---

> **300 mm line · derived from the 150 mm `ZnO-SOP-030` Rev 2.1.** The plating
> **chemistry, two-bath split, per-litre loadings, temperatures, per-area plating
> rates, and the 25 µm total thickness target are identical** to the 150 mm
> procedure — only the **substrate blank, vessel, bath volume, reagent masses, and
> fixtures** scale with the larger wafer. All dimensions come from
> `300mm-datum-reference.md`; this SOP does not restate them independently.

---

# Working Procedure & Specification

## Two-Step Electroless Nickel-Phosphorus Plating of Seeded ZnO Nanotips (300 mm)
### Mid-P near-neutral strike + High-P acid bulk — 25 µm total

| Field | Value | Field | Value |
|---|---|---|---|
| Document no. | ZnO-SOP-030-300 | Revision | 1.0 |
| Effective date | ____________ | Supersedes | — (new; derived from 150 mm Rev 2.1) |
| Author | Croft Swonyoung | Approved by | ____________ |
| Predecessor step | ZnO-SOP-020-300 (APTES + Ag seeding) | Next step | ZnO-SOP-040-300 (caustic strip / release) |

---

## 1. Purpose and scope

This procedure deposits a two-layer electroless nickel-phosphorus (Ni-P) coating onto the seeded ZnO nanotip surface, building a coherent, low-stress metal replica that will later be released as a free-standing foil. Plating proceeds in two baths:

- **Step 1 — mid-P, near-neutral, low-temperature strike.** Gentle initiation on the Ag seeds that fully covers the amphoteric ZnO/Zn substrate before it can be attacked.
- **Step 2 — high-P, low-pH, high-temperature bulk.** Builds the majority of the thickness as a corrosion-resistant, low-stress, amorphous layer that survives the downstream NaOH strip and stays flat when freed.

**Target:** 25 µm total nickel thickness (~2–3 µm Step 1 + balance Step 2), one face only. *(Thickness is diameter-independent — unchanged from the 150 mm line.)*

**Substrate:** Ag-seeded ZnO nanotips on zinc foil, **0.15 mm × ⌀306 round blank** (⌀280 active area, backing a 300 mm silicon wafer — see `300mm-datum-reference.md`), mounted in a carrier that masks the reverse face; from ZnO-SOP-020-300.

**Output:** a 25 µm Ni-P-coated coupon ready for temporary-carrier mounting and the NaOH strip.

---

## 2. Definitions and interpretation

- **Phosphorus is set by pH.** In hypophosphite-reduced Ni-P, lower bath pH gives higher co-deposited phosphorus. Hence Step 1 (near-neutral) yields mid-P (~5–8 %) and Step 2 (acidic) yields high-P (~10–12 %). This is the mechanism behind the two-bath split, not an incidental difference.
- **Strike-then-bulk.** Step 1 exists to protect the substrate: it must be **continuous and pinhole-free** before Step 2, because the low-pH, high-temperature Step 2 bath would attack any exposed ZnO or Zn. Do not enter Step 2 until Step 1 coverage is confirmed. *(Over the larger ⌀280 field, verify coverage across the whole face, not just the centre — see §6.3 and §8.)*
- **Autocatalytic transfer.** Once Step 1 lays down a nickel surface, Step 2 plates directly onto that nickel (electroless Ni is autocatalytic). Only a rinse and, if needed, a brief re-activation are required between baths — no re-seeding.
- **Why high-P for the bulk.** High-P Ni-P is amorphous, low internal stress (so the freed foil does not curl), and broadly corrosion-resistant. Its resistance to the specific NaOH strip conditions must still be **qualified experimentally** (see ZnO-SOP-040-300); keep the strip minimal.
- **Stabiliser — bismuth.** The Step 2 stabiliser is trace bismuth(III), the established lead-free route used in ELV/RoHS-compliant commercial EN baths, replacing lead acetate (and the thiourea fallback, itself a suspected carcinogen). Bi performs the same catalytic-poison stabilising role at ~0.5–1 ppm but runs a **narrower operating window** than Pb: both under-dose (decomposition risk) and over-dose (poisoned, slow, stressed deposit) are nearer. First-run re-qualification is mandatory (§7).
- **Galvanic caution.** Bare Zn in an electroless bath cements nickel and dissolves zinc. Coverage of the tips by the seeded layer plus prompt Step 1 initiation is the mitigation; keep exposed Zn masked.
- **Loading, not diameter, sizes the bath.** The Ni-P thickness target is diameter-independent, but the *plated area* is ~4.6× the 150 mm coupon. Bath volume must scale with area to hold the same per-litre metal reserve (loading, §5.3) — this is the governing new-at-300 mm constraint on uniform, complete plating.

---

## 3. Health, safety and environment

Consult the SDS for each reagent before starting. Key hazards:

- **Nickel salts (nickel sulfate)** — carcinogenic by inhalation, skin sensitiser, toxic, aquatic hazard. Avoid dust and aerosols; gloves and eye protection; work over containment. At 300 mm the per-bath nickel-salt mass is ~4× (§5.1a) — weigh and handle the larger charges with proportionate care.
- **Sodium hypophosphite** — can liberate **phosphine (PH₃, highly toxic)** if a bath overheats, decomposes, or is contaminated; run baths in a fume hood, do not overheat, and never let a bath go stagnant/decompose. Dry hypophosphite is an oxidiser-incompatible fire risk. Note the bismuth stabiliser's narrower window makes decomposition-margin qualification (§7) part of the phosphine-risk control. **The larger ~8–12 L bath heats more slowly and less evenly (§4.2/§7); a local hot spot decomposes a bath — control and map temperature before trusting a big charge.**
- **Bismuth stabiliser (trace)** — bismuth salts are markedly lower-toxicity than the lead they replace and are not classified carcinogens; still handle the stock with normal chemical hygiene and dose by micro-addition. The nitric- or lactic-acid stock solution is corrosive/irritant.
- **Hot acidic bath (Step 2, 85–90 °C, pH ~4.5)** — burn and fume hazard; fume hood; vented, loosely covered vessel. The 300 mm bath is ~4× larger and heavier (~8–12 kg of hot solution) — use a stable, well-supported vessel and safe lifting practice.
- **Hydrogen** — evolved at the plating surface; keep ventilated, no ignition sources.
- **PPE:** nitrile gloves, safety goggles, lab coat; all baths in a fume hood.
- **Waste:** nickel- and phosphite-bearing solutions are regulated heavy-metal waste (Step 2 additionally carries trace Bi — still segregated, but lead-free). Collect spent baths and rinses separately by bath; **volumes are ~4× the 150 mm line — size collection accordingly.** Do not drain-dispose; treat/dispose per local regulations.

---

## 4. Materials, reagents and equipment

### 4.1 Reagents

**Common:** deionised water (Type I/II), dilute H₂SO₄ and dilute NaOH for pH adjustment, dilute H₂SO₄ (~2–5 %) for optional inter-stage activation.

**Step 1 (mid-P, near-neutral):**
- Nickel sulfate hexahydrate, NiSO₄·6H₂O
- Sodium hypophosphite monohydrate, NaH₂PO₂·H₂O
- Sodium citrate dihydrate (complexant/buffer)
- Glycine (secondary complexant)

**Step 2 (high-P, acidic):**
- Nickel sulfate hexahydrate, NiSO₄·6H₂O
- Sodium hypophosphite monohydrate, NaH₂PO₂·H₂O
- Lactic acid (complexant)
- Sodium acetate (buffer)
- Stabiliser: bismuth(III) nitrate pentahydrate, Bi(NO₃)₃·5H₂O (M = 485.07 g/mol), dosed from an acidic stock solution (§5.2a) — or a commercial Bi-based EN stabiliser concentrate per its TDS. **Lead acetate and thiourea are not permitted.**

### 4.2 Equipment

- Two dedicated heated baths (hotplate or immersion heater) with stable control, **sized for the larger ~8–12 L charge**; **do not share vessels between Step 1 and Step 2** (dragout cross-contaminates). At this volume prefer a distributed or immersion heater over a single hotplate footprint — **the bigger bath is slower to reach temperature and harder to hold uniform** (see §7); allow extra heat-up time and confirm even temperature across the vessel before loading.
- Calibrated thermometer/thermocouple per bath (place the probe near the coupon, not just at the vessel wall — check for centre-to-edge and top-to-bottom gradients in the larger bath); pH meter.
- Fume hood; loosely covered inert (glass/PP/PTFE) vessels sized to submerge the ⌀306 coupon in its round carrier (carrier outer ⌀350 per `300mm-datum-reference.md`) — **inner ⌀ ~380–410 mm**, ~8–12 L working volume, with clearance.
- Continuous or periodic filtration (1–5 µm), mild **and uniform** agitation (air sparge or gentle mechanical) — even agitation over the whole ⌀280 face matters more at this size (§7).
- Micropipette / micro-burette for stabiliser stock dosing.
- Substrate carrier (ZnO-DR-006-300 bonding/masking set or equivalent) masking the reverse face; PTFE-tipped tweezers; analytical balance able to weigh the larger reagent charges; timer; DI rinse stations sized for the ⌀306 coupon.
- Thickness metrology (XRF or cross-section SEM) and P-content metrology (EDS/XRF), **sampling multiple sites across the ⌀280 field**.

---

## 5. Bath specifications

*(All per-litre loadings, pH, temperatures, deposit P content, per-area rates, and target thicknesses below are **unchanged from the 150 mm line**. Only bath volume and total reagent mass scale — see §5.1a and §5.3.)*

### 5.1 Step 1 — mid-P, near-neutral, low-temperature strike

| Parameter | Specification | Notes / tolerance |
|---|---|---|
| NiSO₄·6H₂O | 28 g/L | nickel source |
| NaH₂PO₂·H₂O | 27 g/L | reducing agent |
| Sodium citrate dihydrate | 18 g/L | complexant + buffer |
| Glycine | 10 g/L | secondary complexant |
| pH | 6.5–7.0 | near-neutral; adjust minimally |
| Temperature | 65–70 °C | "low" temperature step |
| Deposit P content | ~5–8 wt% | mid-P |
| Deposition rate | ~5–8 µm/hr | qualify on first run |
| Target thickness | 2–3 µm | **continuous, pinhole-free cover** |
| Time | ~20–30 min | to target coverage |

> pH adjustment: keep near-neutral with the citrate buffer. **Avoid ammonia and strong caustic** while any ZnO/Zn is still exposed — they attack the substrate. Make only small dilute additions.

### 5.1a Reagent masses by bath volume (representative)

Per-litre loadings are unchanged; total mass scales with the larger volume. Representative charges (scale linearly, mass = g/L × litres):

| Bath volume | NiSO₄·6H₂O (28 g/L) | NaH₂PO₂·H₂O (27 g/L) | Na citrate·2H₂O (18 g/L) | Glycine (10 g/L) |
|---|---|---|---|---|
| 8 L | 224 g | 216 g | 144 g | 80 g |
| 10 L | 280 g | 270 g | 180 g | 100 g |
| 12 L | 336 g | 324 g | 216 g | 120 g |

*(Step 2 masses: NiSO₄·6H₂O 28 g/L, NaH₂PO₂·H₂O 32 g/L, lactic acid 28 g/L, sodium acetate 10 g/L — e.g. for 10 L: 280 g / 320 g / 280 g / 100 g; Bi per §5.2a.)*

### 5.2 Step 2 — high-P, low-pH, high-temperature bulk

| Parameter | Specification | Notes / tolerance |
|---|---|---|
| NiSO₄·6H₂O | 28 g/L | nickel source |
| NaH₂PO₂·H₂O | 32 g/L | higher hypophosphite:Ni → higher P |
| Lactic acid | 28 g/L | complexant |
| Sodium acetate | 10 g/L | buffer |
| Stabiliser (Bi from bismuth nitrate) | ~0.5–1 ppm Bi | trace; micro-dose from acidic stock (§5.2a); narrower window than the former Pb — qualify per §7 |
| pH | 4.5–5.0 | acidic → high P |
| Temperature | 85–90 °C | high temperature |
| Deposit P content | ~10–12 wt% | high-P, amorphous, low stress |
| Deposition rate | ~15–20 µm/hr | qualify on first run |
| Target thickness | ~22 µm | balance to 25 µm total |
| Time | ~70–85 min | to target thickness |

#### 5.2a Bismuth stabiliser stock

Bi(NO₃)₃·5H₂O hydrolyses to insoluble basic salts in plain water — **make the stock acidic**. Representative stock: dissolve 100 mg Bi(NO₃)₃·5H₂O in 100 mL of ~5 % lactic acid (or ~1 M nitric acid) → ~0.43 g Bi/L. **Dose is proportional to bath volume** (the target is ppm, i.e. per-litre): per litre of bath, ~2.3 mL of stock gives 1 ppm Bi and ~1.2 mL gives 0.5 ppm — so a **10 L** Step 2 bath takes ~**23 mL** (1 ppm) or ~**12 mL** (0.5 ppm). Add drop-wise with stirring to the fully made-up, still-cool bath, distributing the addition as you stir so the larger volume mixes evenly; never add solid salt directly. Label and date the stock; remake if any precipitate/cloudiness appears.
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

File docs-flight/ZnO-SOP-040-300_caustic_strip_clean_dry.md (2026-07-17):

<!-- Public Domain Dedication: CC0 1.0 Universal -->
> **Public Domain · CC0 1.0 Universal.** Author: **Croft Swonyoung**. To the extent possible under law, the author has waived all copyright and related or neighbouring rights to this document and dedicates it to the public domain worldwide (CC0 1.0). No warranty. See `LICENSE` or <https://creativecommons.org/publicdomain/zero/1.0/>.
>
> Part of the *ZnO nanovoid process* document set (300 mm flying line). Verify file integrity against `CHECKSUMS.sha256`.

---
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

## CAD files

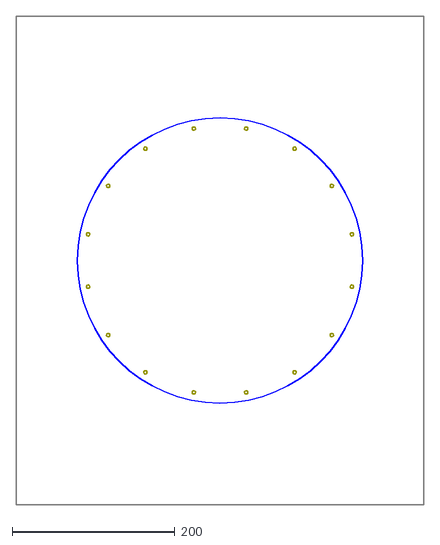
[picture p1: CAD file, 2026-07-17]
docs-flight/ZnO_cut_PP_half_300.dxf
500.0 x 600.0

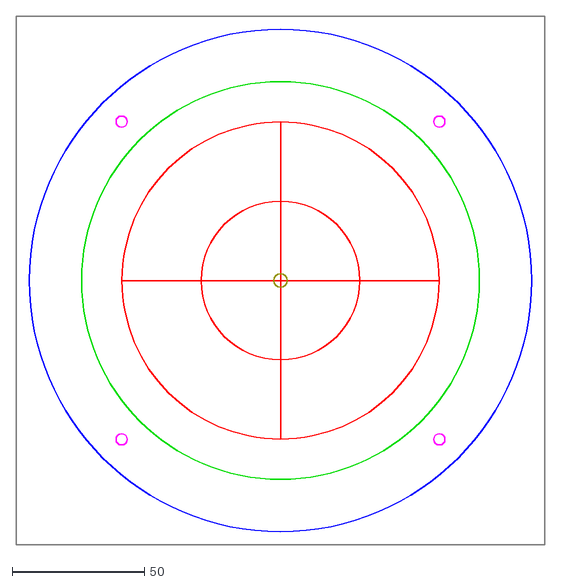
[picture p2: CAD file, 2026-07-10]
docs-rotor/ZnO_cut_platen_alum.dxf
200.0 x 200.0

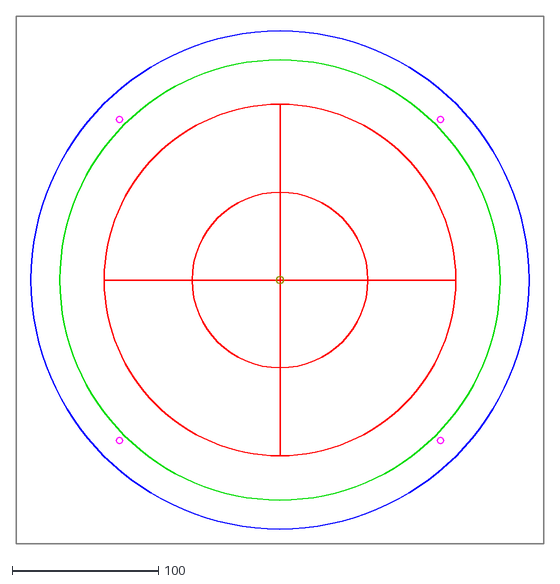
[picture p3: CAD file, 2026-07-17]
docs-flight/ZnO_cut_platen_alum_300.dxf
360.0 x 360.0

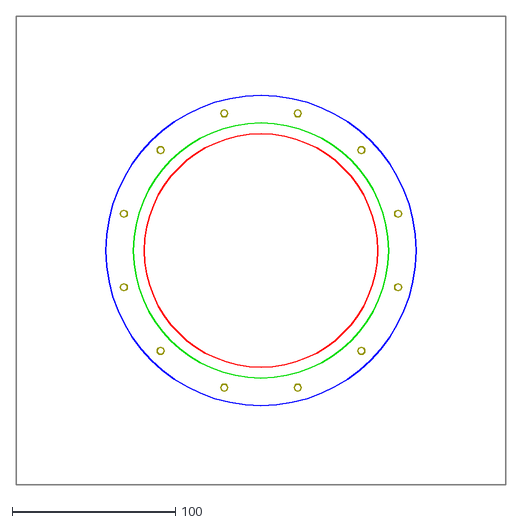
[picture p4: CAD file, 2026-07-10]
docs-rotor/ZnO_cut_PP_half.dxf
300.0 x 287.0

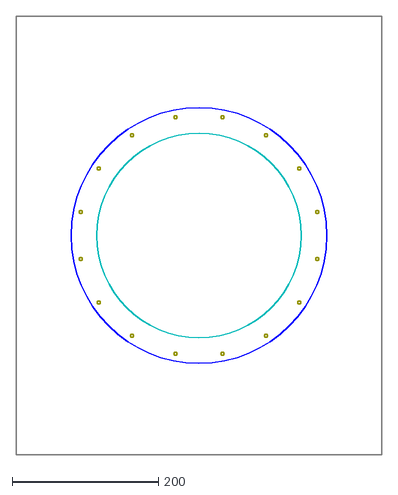
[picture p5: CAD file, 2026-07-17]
docs-flight/ZnO_cut_PP_threeEighth_300.dxf
500.0 x 600.0

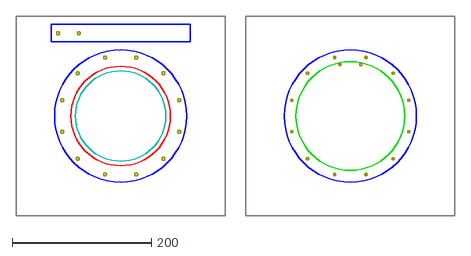
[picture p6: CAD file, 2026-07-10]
docs-rotor/ZnO_cut_PVDF_quarter.dxf
630.0 x 287.0

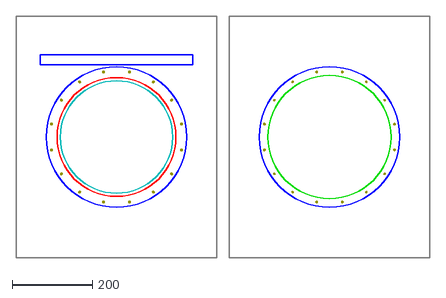
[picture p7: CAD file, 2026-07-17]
docs-flight/ZnO_cut_PVDF_quarter_300.dxf
1030.0 x 600.0

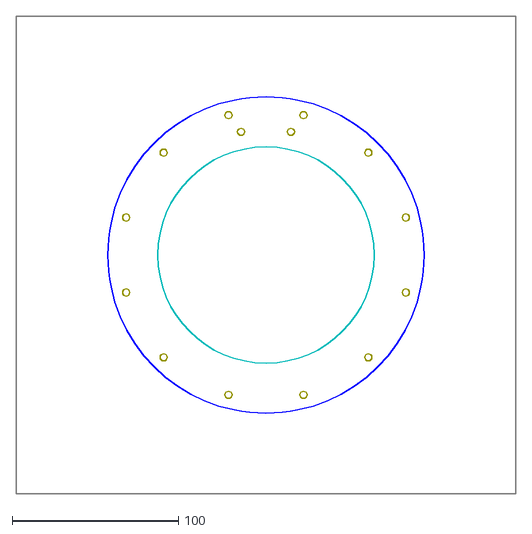
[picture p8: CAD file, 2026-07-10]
docs-rotor/ZnO_cut_PP_threeEighth.dxf
300.0 x 287.0

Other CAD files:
docs-rotor/ZnO_cut_frame_PVDF.dxf

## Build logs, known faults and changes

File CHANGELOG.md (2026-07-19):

# Changelog — ZnO Nanovoid Process document set

All notable changes to this document set are recorded here. The set is dedicated
to the public domain under CC0 1.0 (see `LICENSE`). Versions follow the git tags;
the Zenodo **concept DOI** `10.5281/zenodo.21224278` always resolves to the
latest published version.

## [2.3]— 2026-07-19

### Changed — ZnO seed layer added to the growth SOPs (both lines)
`ZnO-SOP-010` (150 mm, → **Rev 3.0**) and `ZnO-SOP-010-300` (300 mm, → **Rev 1.1**)
gain a **ZnO seed layer** ahead of hydrothermal growth: 5 mM zinc acetate dihydrate
in absolute ethanol, 3–5 flood coats (ethanol rinse each), annealed 300 ± 25 °C /
20–30 min in air. The zinc-acetate-derived nanocrystal seeds carry a (0001)-up
texture, decoupling rod orientation from the rolled foil's random grain
orientations — targeting a c-axis-vertical array with a tighter size and tilt
distribution than the previous self-seeded (bare-foil) nucleation. Title changes
from *Self-Seeded* to *Seeded*; the acetic light etch is retained as surface prep
with a hard rule of **no acid contact after seeding** (ZnO dissolves in weak
acids). Seeded runs re-enter first-run calibration: the same 10 mM depletion
charge split across more rods trends denser/shorter/thinner. Naming discipline:
"ZnO seed layer" (SOP-010) vs. "silver seeding" (SOP-020) — different steps.

Propagated through the set: the **shop packets** `ZnO-SP-001` (→ **Rev 2.1**) and
`ZnO-SP-001-300` (→ **Rev 1.1**) carry the seed layer at routing op 10 (gate now
includes seed-tint uniformity and tilt), the document index revs, the growth
station (300 °C seed anneal; flat Al anneal plate — ≥ ⌀320 with oven preferred at
300 mm), purchasing (zinc acetate dihydrate + absolute ethanol), and open item O3
(first seeded run resets the growth baseline). `300mm-re-derivation-plan.md`
notes the carry-over and the rule that `-300` docs track rotor-line SOP revs.
`CHECKSUMS.sha256` regenerated for all revised files.

## [2.2] — 2026-07-17

Builds on the released **v2.1** (2026-07-15). The rotor-line ruggedization and the
integration SOPs (SOP-070/080) shipped in v2.1; this release reorganises the set
into two directories and adds the second, 300 mm line.

### Added — 300 mm flying-machine line (`docs-flight/`)
A complete second fabrication line at 300 mm wafers, for the flying-machine
application, re-derived from the 150 mm line on its own locked datum
(`300mm-datum-reference.md`: wafer ⌀300 × 0.775 mm, active ⌀280, zinc blank ⌀306,
carrier ⌀350). The **chemistry is identical**; geometry, bath volumes (~4×), masses
(~145 g/cell), and tooling scale with the larger wafer. Contents:
- **Fabrication SOPs** `ZnO-SOP-010-300 … 060-300` (growth → seed → plate → strip →
  wafer bond → vacuum stack close, including the Appendix A ruggedization at 300 mm).
- **Design references** `ZnO-DR-001-300 … 006-300` and the **shop packet** `ZnO-SP-001-300`.
- **DXF cut set** `ZnO_cut_*_300.dxf` (carrier ⌀350 / window ⌀280 / bolt circle ⌀330
  ×16 M4; ⌀300 wafer chuck) with matching **to-scale SVG plans**, both emitted by a
  shipped, reproducible generator **`gen_round_dxf_300.py`** and validated with ezdxf.
- The **flying-integration procedure** `ZnO-SOP-080-300` remains a 150 mm-based
  **seed**, pending a defined flyer (airframe, measured per-puck thrust, T/W).

Naming: the 150 mm step numbers with a `-300` suffix. The 300 mm choice is for
handling/throughput — thrust-to-weight is ~scale-invariant, not a better lift ratio.

### Changed — Two end-use lines, one set
The set was reorganised into two documentation directories under one publication:
- **`docs-rotor/`** — the 150 mm **rotor / generator** line (the former `docs/`,
  now including SOP-070); complete at 19 files.
- **`docs-flight/`** — the 300 mm **flying-machine** line (new; detailed above).
  Because the wafer size cascades through the whole fabrication chain, this line is
  built on its own locked datum.

One README/LICENSE/NOTICE/MANIFEST/CHANGELOG/CHECKSUMS covers both — a single
publication and a single Zenodo deposit, not two.

### Changed — Rotor line (`docs-rotor/`) refinements
- **SOP-070** thrust goal corrected to **50 lbf ≈ 222 N** (→ τ ≈ 102 N·m, ≈5.3 kW at
  500 rpm); the earlier "50 N" figure was an lbf→N slip.
- **SOP-080** (flying-vehicle integration) moved out of the rotor set into
  `docs-flight/` as the 300 mm-line seed (`ZnO-SOP-080-300`), since the flyer uses
  300 mm wafers.

### Changed — Housekeeping
- Directories: `docs/` → `docs-rotor/`; added `docs-flight/`.
- `MANIFEST.md`, `README.md`, `NOTICE.md`, and `TIMESTAMPING.md` updated to match.
- `CHECKSUMS.sha256` regenerated over both directories and verified (`sha256sum -c`
  passes on all entries).

## [2.1] — 2026-07-15

First application-specific mounting / integration work, in the single `docs/`
layout (before the two-line reorganisation of v2.2).

### Added — Ruggedization variant (SOP-060 Appendix A)
An application-agnostic option for units that will experience in-service inertial
loading at arbitrary orientation: a pre-cured, low-outgassing platinum-silicone
edge-cushion inside the vacuum envelope (protecting the brittle wafer edges) and an
outboard, filled, low-exotherm epoxy carrier pot (mounting datum + centre-of-gravity
budget). Sized to a design acceleration, with a spinning-rotor case (~128 × gravity)
as the bounding example. The baseline measurement brick omits both.

### Added — Application-integration procedures (SOP-070, SOP-080)
- **SOP-070** — a self-driven, thrust-vectored rotor test rig: integration,
  balancing, fail-safe braking/signal logic, and a commissioning sequence with
  built-in confound controls (null / drive / reversal / balanced-pair) and
  honest-null reporting.
- **SOP-080** — a staged flying-vehicle demonstrator: constrained thrust/lift
  measurement first, with free flight gated behind measured thrust-to-weight,
  demonstrated control, and a verified fail-safe.

Both are written to be safe and informative whether or not any net force exists,
and claim nothing.

## [2.0] — 2026-07-09

### Changed — Architecture migration (rectangular → round; Si-wafer / common vacuum)
The stack was rebuilt around a single-side-polished 150 mm silicon-wafer backer
and a zero-gap, common-vacuum design:
- Each electroless Ni-P foil is silicone-bonded (high-phosphorus face) to the
  unpolished back of a silicon wafer; cells stack with each foil's working (void)
  face in direct mechanical contact against the next cell's polished silicon
  face — no per-interface bond.
- One common vacuum for the whole stack, held by a getter inside a conformal
  metallized (vacuum-insulation-panel-grade) barrier envelope; atmospheric
  pressure supplies the preload.
- Retired: the aluminium backer plate, the nitrogen-filled spacer gap, and the
  per-cell butyl seals.
- SOP-010 through SOP-060 and the shop packet (SP-001) updated to the round
  156 mm blank / 130 mm active datum and 0.15 mm zinc; all six design-reference
  (DR) docs rewritten to Rev 2.0 and all five DXF cut files regenerated (the
  butyl clamp frame retired; the aluminium platen repurposed as a flat 150 mm
  wafer vacuum chuck).

## [1.x] — initial release

First public-domain release of the fabrication process (earlier rectangular,
nitrogen-filled architecture), archived on Zenodo under concept DOI
`10.5281/zenodo.21224278`.

---

**Scope.** These documents specify the fabrication of a stacked nickel "nanovoid"
article and rigs to test it. Whether a finished stack produces any net force is
an open, unmeasured hypothesis — to be settled by direct measurement with
controls, not asserted here.

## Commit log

2026-07-08 v1.1 — SOP-040 dilute strip + 10 h rinse soak; integrity fixes
    - SOP-040: drop caustic strip to 0.2 M NaOH (~10x slower, gentler on the
    Ni-P; temperature held), and add a ~10 h static DI soak to the rinse.
    - README: record Zenodo DOI 10.5281/zenodo.21224278.
    - CHECKSUMS.sha256: rehash SOP-040 and README, and fix the stale NOTICE.md
    line (the v1 manifest was frozen before the dedication date was filled in,
    so v1's own `sha256sum -c` failed on NOTICE.md).
    - .gitattributes: freeze all files as binary (`* -text`) and disable
    autocrlf so the SHA-256 checksums verify identically on every platform.
    The timestamp proof (CHECKSUMS.sha256.ots) is regenerated separately after
    re-stamping the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
2026-07-10 v2.0 — silicon-wafer / common-vacuum architecture (round cut-set)
    Replace the aluminium-plate / N2-fill / butyl-seal design with a
    silicon-wafer-backed, zero-gap, common-vacuum stack. Round 150 mm
    wafer-scale cut-set (0.15 mm Zn, D156 blank / D130 active); chemical
    de-rim + single final void clean; parameterised N (<=117), shiny-Si-down
    orientation, silicone-band retaining cartridge, 1/8in Al platens.
    Normalised SOP/DR filenames; regenerated MANIFEST and CHECKSUMS.
    [ZnO_cut_PP_half.dxf, ZnO_cut_PP_threeEighth.dxf, ZnO_cut_PVDF_quarter.dxf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]
2026-07-15 Version 2.1. Thoughts toward final application-specific mounting
2026-07-17 Release v2.2: add the 300 mm flying-machine line; two docs directories
    One publication, two end-use lines built from the same fabrication chemistry:
    * docs-rotor/ (150 mm rotor / generator line) — the former docs/. Adds the
    SOP-060 Appendix A application-agnostic ruggedization variant (edge-cushion +
    carrier pot) and SOP-070 rotor integration & commissioning.
    * docs-flight/ (300 mm flying-machine line, NEW) — a complete second fab chain
    re-derived on its own locked datum (300mm-datum-reference.md): SOP-010-300 …
    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
    [ZnO_cut_PP_half.dxf, ZnO_cut_PP_half_300.dxf, ZnO_cut_PP_threeEighth.dxf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]
